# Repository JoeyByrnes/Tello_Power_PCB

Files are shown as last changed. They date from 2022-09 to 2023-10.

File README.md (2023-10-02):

# Tello Power PCB
Hardware Design Files for Tello Power Regulation/Distribution PCB

## Main Power PCB
<hr>
<br>
<p align="center">
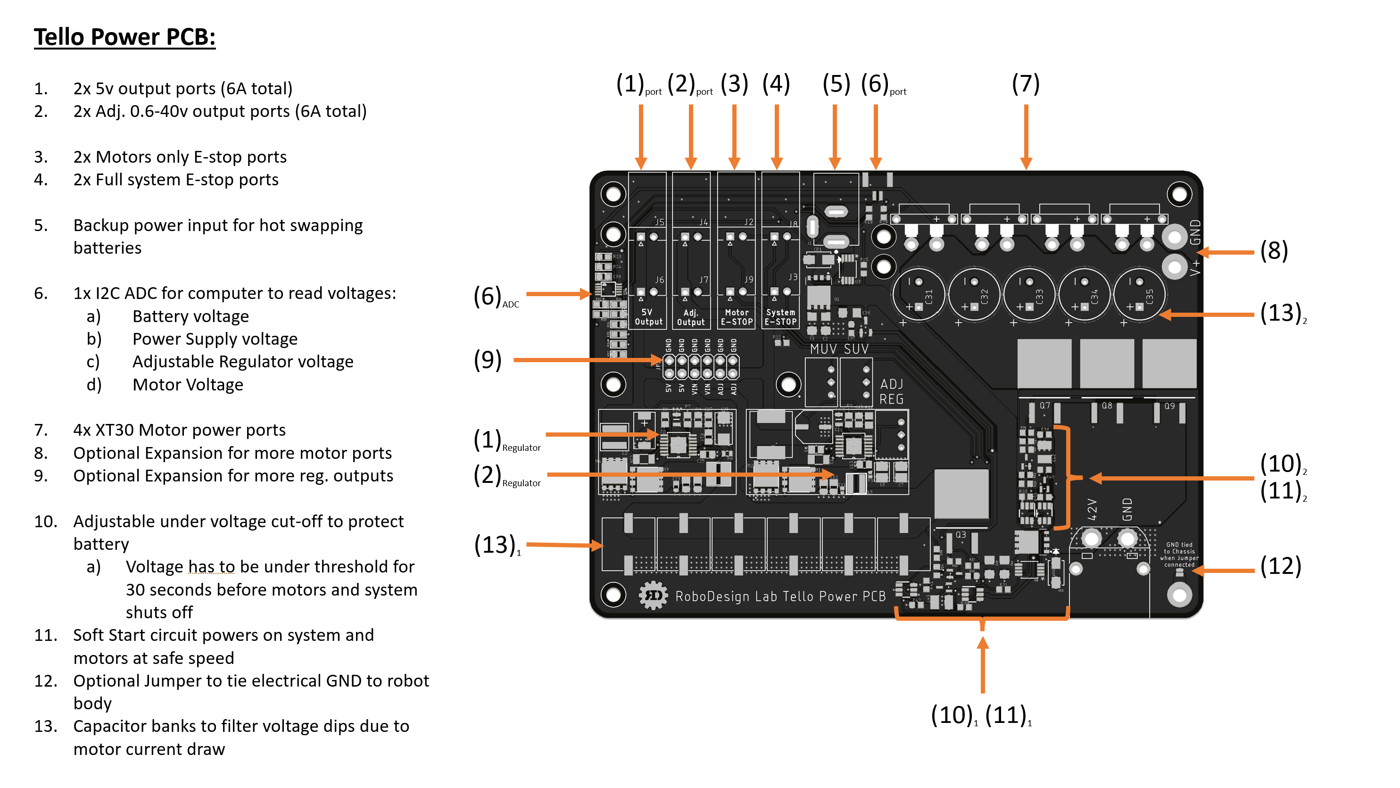
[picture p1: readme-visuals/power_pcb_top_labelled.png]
  
</p>
<p align="center">
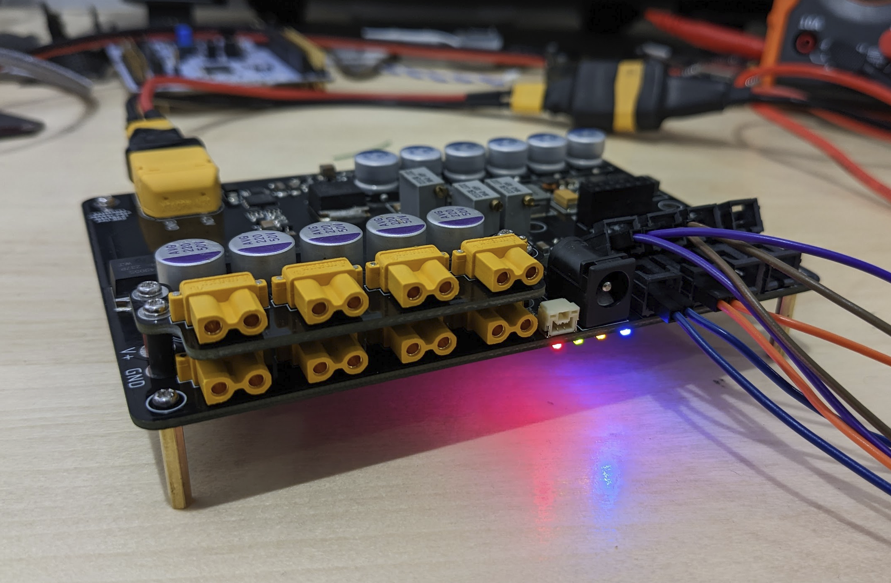
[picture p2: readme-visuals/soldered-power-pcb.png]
  
</p>
<p align="center">
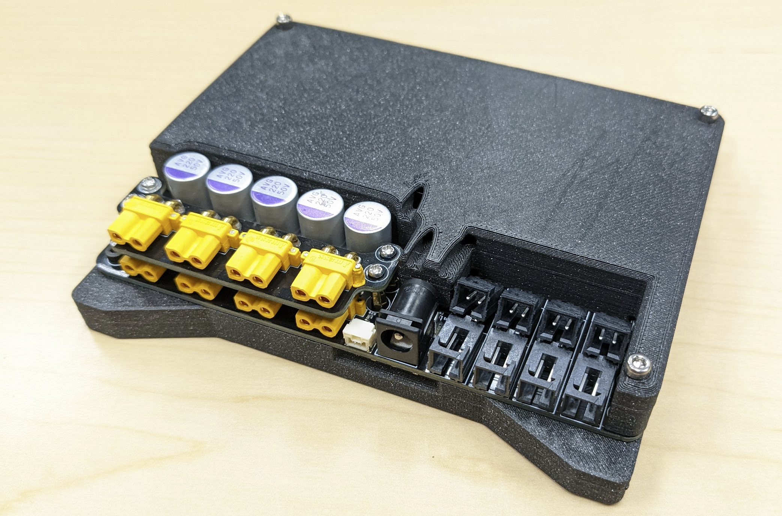
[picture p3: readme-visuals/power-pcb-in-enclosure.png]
  
</p>

<p align="center">
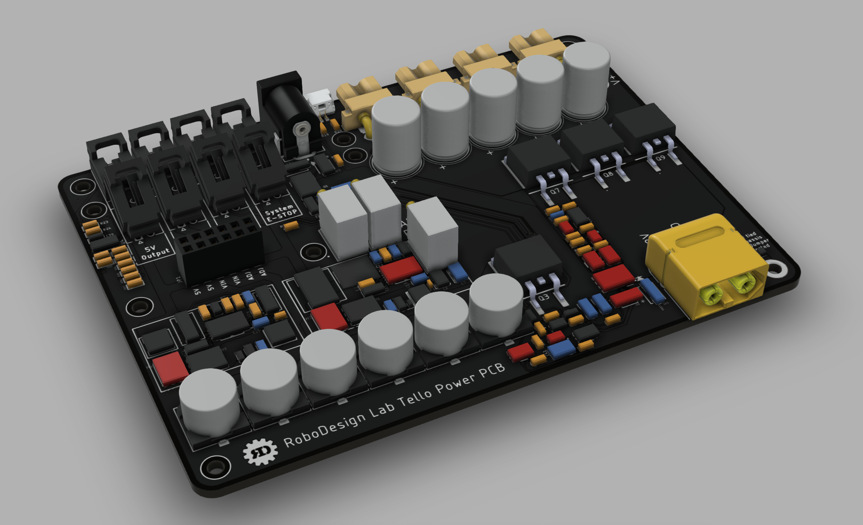
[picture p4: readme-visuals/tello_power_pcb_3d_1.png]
  
</p>
<p align="center">
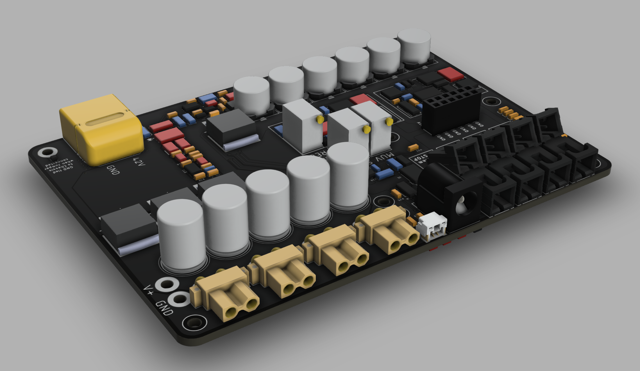
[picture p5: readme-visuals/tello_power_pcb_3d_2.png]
  
</p>
<p align="center">
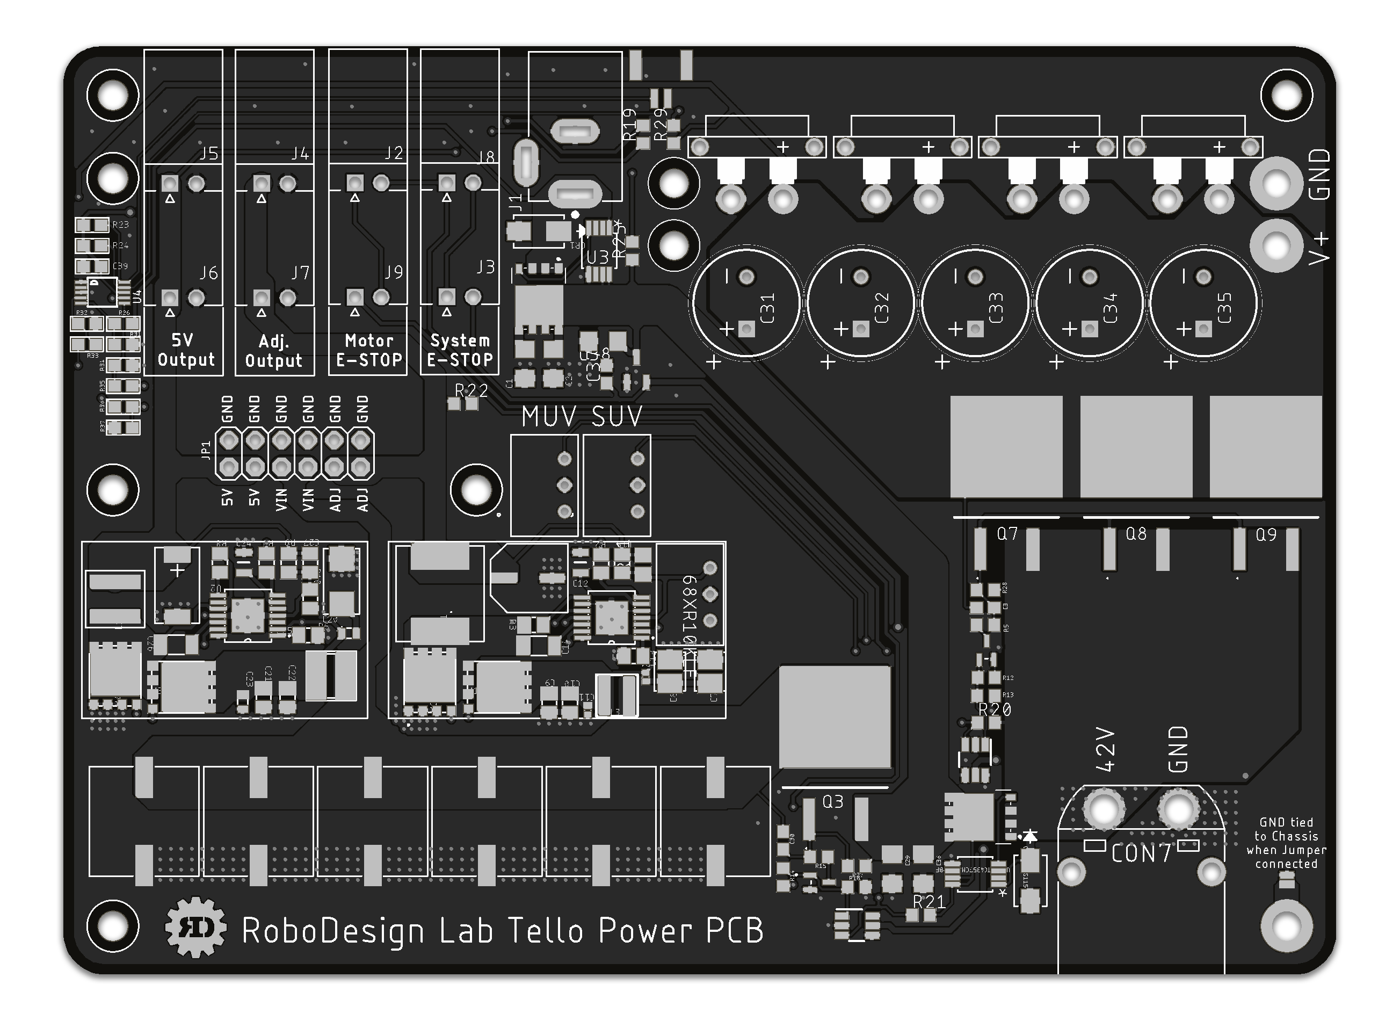
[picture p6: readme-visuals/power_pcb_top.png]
  
</p>
<p align="center">
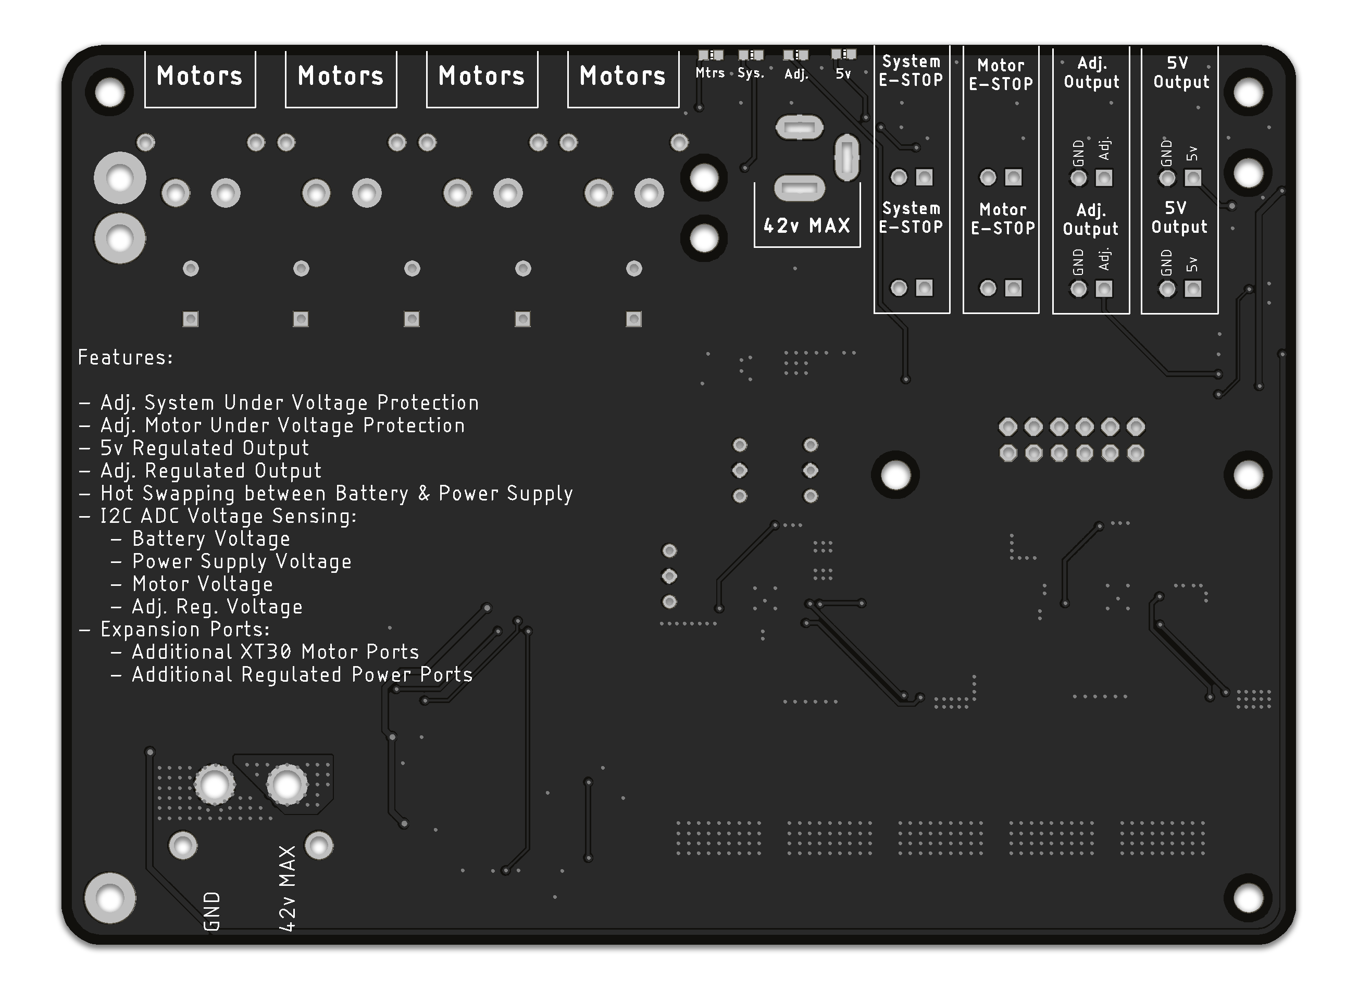
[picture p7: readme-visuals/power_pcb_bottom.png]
  
</p>

<br>

## XT30 Expansion PCB
<hr>
<br>
<p align="center">
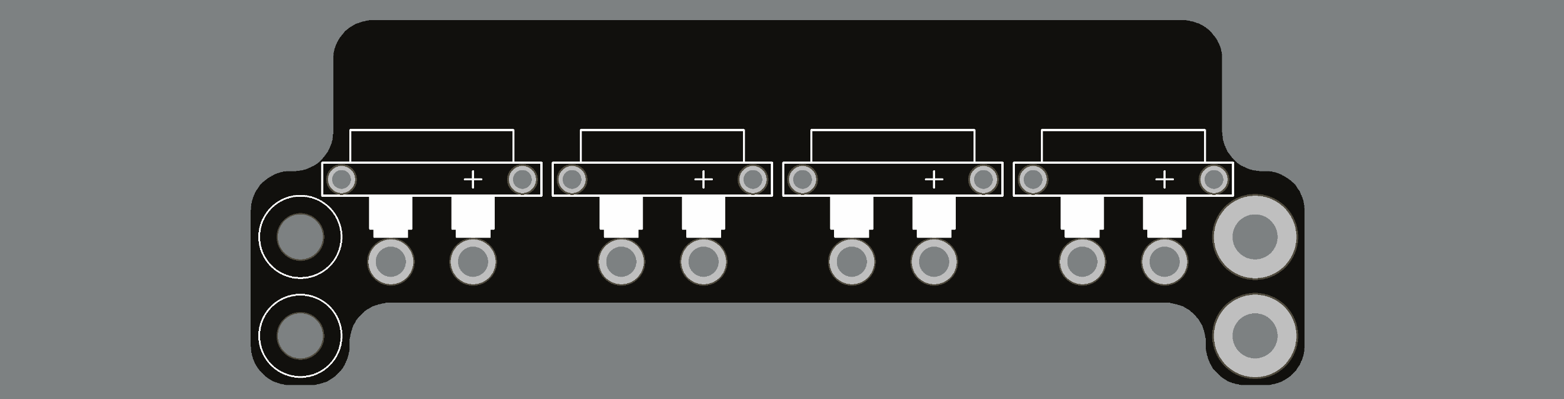
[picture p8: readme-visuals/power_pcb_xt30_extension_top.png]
  
</p>

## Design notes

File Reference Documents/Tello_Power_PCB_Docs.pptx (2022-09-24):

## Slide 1

Tello Power PCB:
1. 2x 5v output ports (6A total)
2. 2x Adj. 0.6-40v output ports (6A total)
3. 2x Motors only E-stop ports
4. 2x Full system E-stop ports
5. Backup power input for hot swapping batteries
6. 1x I2C ADC for computer to read voltages:
  a. Battery voltage
  b. Power Supply voltage
  c. Adjustable Regulator voltage
  d. Motor Voltage
7. 4x XT30 Motor power ports
8. Optional Expansion for more motor ports
9. Optional Expansion for more reg. outputs
10. Adjustable under voltage cut-off to protect battery
  a. Voltage has to be under threshold for 30 seconds before motors and system shuts off
11. Soft Start circuit powers on system and motors at safe speed
12. Optional Jumper to tie electrical GND to robot body
13. Capacitor banks to filter voltage dips due to motor current draw

(1)port

(2)port

(3)

(4)

(5)

(6)port

(7)

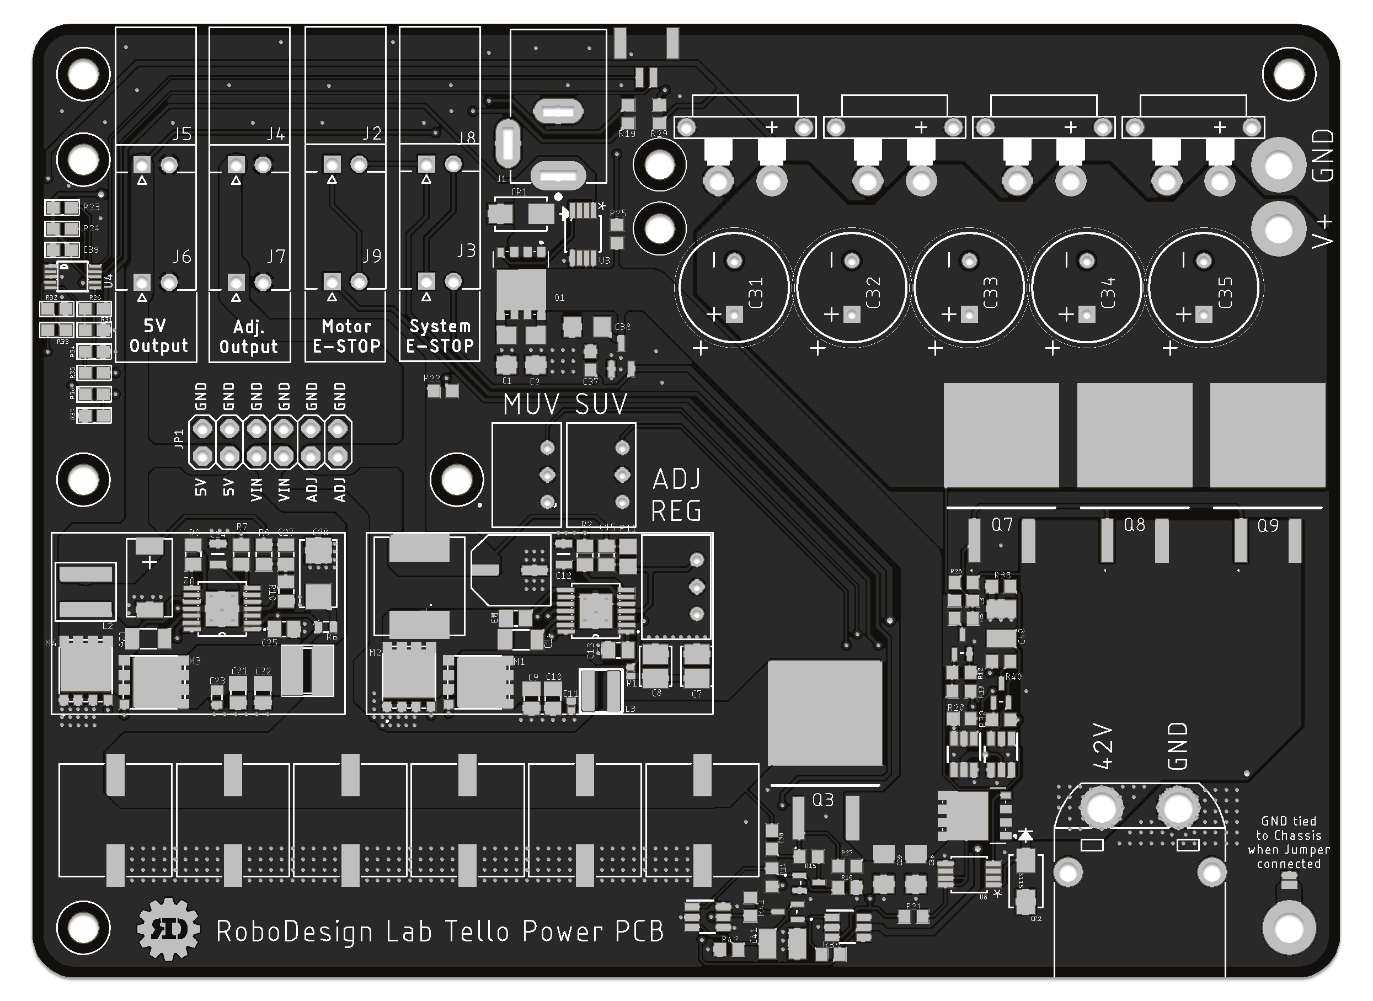
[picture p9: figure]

(8)

(6)ADC

(13)2

(9)

(1)Regulator

(2)Regulator

(10)2

(13)1

(11)2

(12)

(10)1

(11)1

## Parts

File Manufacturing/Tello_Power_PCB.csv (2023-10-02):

Qty | Value | Device | Package | Parts | Description | ARROW_PART_NUMBER | ARROW_PRICE-STOCK | BUILT_BY | CAP | COPYRIGHT | CUI_PURCHASE_URL | DATASHEETURL | DCR | DESCRIPTION | DIGI-KEY_PART_NUMBER | DIGI-KEY_PART_NUMBER_1 | DIGI-KEY_PART_NUMBER_2 | DIGI-KEY_PART_NUMBER_3 | ESR | FREQUENCY | HEIGHT | IDC | IDSMAX | IMAX | IRMS | L | MANUFACTURER_NAME | MANUFACTURER_PART_NUMBER | MF | MFR_NAME | MKTG_PACKAGE | MOUSER_PART_NUMBER | MOUSER_PRICE-STOCK | MOUSER_TESTING_PART_NUMBER | MOUSER_TESTING_PRICE-STOCK | MP | NSID | PACKAGE | POPULARITY | POWER | PURCHASE-URL | QGTYP | QUANTITY | RDSON45 | RDSONAT10V | REFDES | RESISTANCE | RS_PART_NUMBER | RS_PRICE-STOCK | SOURCELIBRARY | SPICEPREFIX | TOLERANCE | TYPE | VDC | VDSMAX | VENDOR
4 |  | LED_LEDCHIP-LED0603 | LED_CHIP-LED0603 | LED1, LED2, LED3, LED4 | LED |  |  |  |  |  |  |  |  |  |  |  |  |  |  |  |  |  |  |  |  |  |  |  |  |  |  |  |  |  |  |  |  |  | 0
1 |  | PINHEAD_PINHD-2X6 | PINHEAD_2X06 | JP1 | PIN HEADER |  |  |  |  |  |  |  |  |  |  |  |  |  |  |  |  |  |  |  |  |  |  |  |  |  |  |  |  |  |  |  |  |  | 1
1 | 1 | 12V--LM3150_CRCW04021R00FKED | 12V--LM3150_0402 | R1 |  |  |  |  |  |  |  |  |  |  |  |  |  |  |  |  |  |  |  |  |  |  | VishayDale | CRCW04021R00FKED |  |  |  |  |  |  |  |  |  |  |  | 0.063 |  |  |  |  |  |  | 1.0 |  |  |  |  | 1.0 |  |  |  | VishayDale
1 | 1.37k | 12V--LM3150_ERJ-6ENF1371V | 12V--LM3150_0805:1 | R3 |  |  |  |  |  |  |  |  |  |  |  |  |  |  |  |  |  |  |  |  |  |  | Panasonic | ERJ6ENF1371V |  |  |  |  |  |  |  |  |  |  |  | 0.125 |  |  |  |  |  |  | 1370.0 |  |  |  |  | 1.0 |  |  |  | Panasonic
1 | 1.58k | 5V-LM3150MH_ERJ-6ENF1581V | 5V-LM3150MH_0805 | R8 |  |  |  |  |  |  |  |  |  |  |  |  |  |  |  |  |  |  |  |  |  |  | Panasonic | ERJ6ENF1581V |  |  |  |  |  |  |  |  |  |  |  | 0.125 |  |  |  |  |  |  | 1580.0 |  |  |  |  | 1.0 |  |  |  | Panasonic
2 | 100K | RCL_R-US_R0603 | RCL_R0603 | R20, R21 | RESISTOR, American symbol |  |  |  |  |  |  |  |  |  |  |  |  |  |  |  |  |  |  |  |  |  |  |  |  |  |  |  |  |  |  |  |  |  | 77 |  |  |  |  |  |  |  |  |  |  |  | R
2 | 100R | RCL_R-US_R0603 | RCL_R0603 | R40, R41 | RESISTOR, American symbol |  |  |  |  |  |  |  |  |  |  |  |  |  |  |  |  |  |  |  |  |  |  |  |  |  |  |  |  |  |  |  |  |  | 77 |  |  |  |  |  |  |  |  |  |  |  | R
1 | 100m | 5V-LM3150MH_ERJ-3RSFR10V | 5V-LM3150MH_0603 | R6 |  |  |  |  |  |  |  |  |  |  |  |  |  |  |  |  |  |  |  |  |  |  | Panasonic | ERJ3RSFR10V |  |  |  |  |  |  |  |  |  |  |  | 0.1 |  |  |  |  |  |  | 0.1 |  |  |  |  | 1.0 |  |  |  | Panasonic
1 | 100nF | 12V--LM3150_C1005X5R1H104K050BB | 12V--LM3150_0402 | C11 |  |  |  |  | 1.0E7 |  |  | httpsproduct.tdk.comensearchcapacitorceramicmlccinfo?part%5Fno%3DC1005X5R1H104K050BB |  |  |  |  |  |  | 0.039064 |  |  |  |  |  | 0.814669 |  | TDK | C1005X5R1H104K050BB |  |  |  |  |  |  |  |  |  |  |  |  |  |  |  |  |  |  |  |  |  |  |  |  |  | 50.0 |  | TDK
1 | 100nF | 5V-LM3150MH_CGA3E2X7R1H104K080AA | 5V-LM3150MH_0603 | C23 |  |  |  |  | 1.0E7 |  |  | httpsproduct.tdk.comensearchcapacitorceramicmlccinfo?part%5Fno%3DCGA3E2X7R1H104K080AA |  |  |  |  |  |  | 0.0296 |  |  |  |  |  | 0.97199 |  | TDK | CGA3E2X7R1H104K080AA |  |  |  |  |  |  |  |  |  |  |  |  |  |  |  |  |  |  |  |  |  |  |  |  |  | 50.0 |  | TDK
6 | 10K | MICROBUILDER_RESISTOR0603 | MICROBUILDER_0603:1 | R23, R24, R26, R33, R35, R36 | Resistors
4 | 10K | RCL_R-US_R0603 | RCL_R0603 | R5, R12, R15, R16 | RESISTOR, American symbol |  |  |  |  |  |  |  |  |  |  |  |  |  |  |  |  |  |  |  |  |  |  |  |  |  |  |  |  |  |  |  |  |  | 77 |  |  |  |  |  |  |  |  |  |  |  | R
1 | 10k | 5V-LM3150MH_CRCW080510K0FKEA | 5V-LM3150MH_0805 | R10 |  |  |  |  |  |  |  |  |  |  |  |  |  |  |  |  |  |  |  |  |  |  | VishayDale | CRCW080510K0FKEA |  |  |  |  |  |  |  |  |  |  |  | 0.125 |  |  |  |  |  |  | 10000.0 |  |  |  |  | 1.0 |  |  |  | VishayDale
2 | 10uF | 5V-LM3150MH_C2012X5R1V106K085AC | 5V-LM3150MH_0805 | C21, C22 |  |  |  |  | 1.0E5 |  |  | httpsproduct.tdk.comensearchcapacitorceramicmlccinfo?part%5Fno%3DC2012X5R1V106K085AC |  |  |  |  |  |  | 0.002818 |  |  |  |  |  | 3.88676 |  | TDK | C2012X5R1V106K085AC |  |  |  |  |  |  |  |  |  |  |  |  |  |  |  |  |  |  |  |  |  |  |  |  |  | 35.0 |  | TDK
4 | 10uF 50v | RCL_C-EUC1206 | RCL_C1206 | C1, C2, C29, C36 | CAPACITOR, European symbol |  |  |  |  |  |  |  |  |  |  |  |  |  |  |  |  |  |  |  |  |  |  |  |  |  |  |  |  |  |  |  |  |  | 13 |  |  |  |  |  |  |  |  |  |  |  | C
1 | 10µF | MICROBUILDER_CAP_CERAMIC0603 | MICROBUILDER_0603:1 | C39 | Ceramic Capacitors
2 | 15nF | CGA4F2C0G1H153J085AA_CGA4F2C0G1H153J085AA | CGA4F2C0G1H153J085AA_CAPC2012X100N | C12, C24 | Capacitor Auto CGA 0805 50V 15nF C0G |  |  |  |  |  |  |  |  | Capacitor Auto CGA 0805 50V 15nF C0G |  |  |  |  |  |  | 1mm |  |  |  |  |  | TDK | CGA4F2C0G1H153J085AA |  |  |  | 810-CGA4F2C0G1H153J | https://www.mouser.com/Search/Refine.aspx?Keyword=810-CGA4F2C0G1H153J |  |  |  |  |  |  |  |  |  |  |  |  |  |  | 9155168 | https://uk.rs-online.com/web/p/products/9155168
2 | 15uF | 12V--LM3150_C2012X5R1V156M125AC | 12V--LM3150_0805:1 | C9, C10 |  |  |  |  | 1.5E5 |  |  | httpsproduct.tdk.cominfoencatalogdatasheetsmlcc%5Fcommercial%5Fgeneral%5Fen.pdf |  |  |  |  |  |  | 0.001669 |  |  |  |  |  | 5.04984 |  | TDK | C2012X5R1V156M125AC |  |  |  |  |  |  |  |  |  |  |  |  |  |  |  |  |  |  |  |  |  |  |  |  |  | 35.0 |  | TDK
8 | 1719740002_1719740002 | 1719740002_1719740002 | 1719740002_MOLEX_1719740002 | J2, J3, J4, J5, J6, J7, J8, J9 | 2.54mm Pitch SL Header, Single Row, Right-Angle, LCP, Shrouded, Through Hole, Matte Tin (Sn) Plating, 2 Circuits |  |  |  |  |  |  |  |  | Connector Header Through Hole, Right Angle 2 position 0.100 (2.54mm) | WM22662-ND |  |  |  |  |  |  |  |  |  |  |  |  |  | Molex |  |  |  |  |  |  | 1719740002 |  | None |  |  | https://pricing.snapeda.com/search/part/1719740002/?ref=eda
4 | 1K | MICROBUILDER_RESISTOR0603 | MICROBUILDER_0603:1 | R31, R32, R34, R37 | Resistors
5 | 1K | RCL_R-US_R0603 | RCL_R0603 | R13, R14, R19, R30, R39 | RESISTOR, American symbol |  |  |  |  |  |  |  |  |  |  |  |  |  |  |  |  |  |  |  |  |  |  |  |  |  |  |  |  |  |  |  |  |  | 77 |  |  |  |  |  |  |  |  |  |  |  | R
1 | 2.2uF | 12V--LM3150_EMK212BJ225KG-T:1 | 12V--LM3150_0805:1 | C13 |  |  |  |  | 2.2E6 |  |  |  |  |  |  |  |  |  | 0.0 |  |  |  |  |  | 0.0 |  | Taiyo Yuden | EMK212BJ225KGT |  |  |  |  |  |  |  |  |  |  |  |  |  |  |  |  |  |  |  |  |  |  |  |  |  | 16.0 |  | Taiyo Yuden
2 | 2.2uF | 12V--LM3150_TPSB475K035R0700 | 12V--LM3150_3528-21 | C7, C8 |  |  |  |  | 4.7E6 |  |  |  |  |  |  |  |  |  | 0.7 |  |  |  |  |  | 0.314 |  | AVX | TPSB475K035R0700 |  |  |  |  |  |  |  |  |  |  |  |  |  |  |  |  |  |  |  |  |  |  |  |  |  | 35.0 |  | AVX
1 | 2.2uF | 5V-LM3150MH_EMK212BJ225KG-T | 5V-LM3150MH_0805 | C25 |  |  |  |  | 2.2E6 |  |  |  |  |  |  |  |  |  | 0.0 |  |  |  |  |  | 0.0 |  | Taiyo Yuden | EMK212BJ225KGT |  |  |  |  |  |  |  |  |  |  |  |  |  |  |  |  |  |  |  |  |  |  |  |  |  | 16.0 |  | Taiyo Yuden
1 | 2.2uF | RCL_C-EUC0603 | RCL_C0603 | C37 | CAPACITOR, European symbol |  |  |  |  |  |  |  |  |  |  |  |  |  |  |  |  |  |  |  |  |  |  |  |  |  |  |  |  |  |  |  |  |  | 52 |  |  |  |  |  |  |  |  |  |  |  | C
1 | 2.2uF | RCL_C-EUC1206 | RCL_C1206 | C38 | CAPACITOR, European symbol |  |  |  |  |  |  |  |  |  |  |  |  |  |  |  |  |  |  |  |  |  |  |  |  |  |  |  |  |  |  |  |  |  | 13 |  |  |  |  |  |  |  |  |  |  |  | C
1 | 2.2uH | 5V-LM3150MH_XAL5030-222MEB | 5V-LM3150MH_XAL5030 | L2 |  |  |  |  |  |  |  |  | 0.01 |  |  |  |  |  |  |  |  | 9.2 |  |  |  | 2.2E6 | Coilcraft | XAL5030222MEB |  |  |  |  |  |  |  |  |  |  |  |  |  |  |  |  |  |  |  |  |  |  |  |  |  |  |  | Coilcraft
2 | 220uF | RCL_C-EUC1210 | RCL_C1210 | C40, C41 | CAPACITOR, European symbol |  |  |  |  |  |  |  |  |  |  |  |  |  |  |  |  |  |  |  |  |  |  |  |  |  |  |  |  |  |  |  |  |  | 0 |  |  |  |  |  |  |  |  |  |  |  | C
5 | 227AVG050MGBJ_227AVG050MGBJ | 227AVG050MGBJ_227AVG050MGBJ | 227AVG050MGBJ_CAPPRD500W60D1025H1350 | C31, C32, C33, C34, C35 | Aluminum Organic Polymer Capacitors 220uF 50V 20% POLYMER/IC | 227AVG050MGBJ | https://www.arrow.com/en/products/227avg050mgbj/illinois-capacitor?region=nac |  |  |  |  |  |  | Aluminum Organic Polymer Capacitors 220uF 50V 20% POLYMER/IC |  |  |  |  |  |  | 13.5mm |  |  |  |  |  | Cornell Dubilier | 227AVG050MGBJ |  |  |  | 598-227AVG050MGBJ | https://www.mouser.co.uk/ProductDetail/CDE-Illinois-Capacitor/227AVG050MGBJ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
4 | 2K | RCL_R-US_R0603 | RCL_R0603 | R25, R27, R28, R29 | RESISTOR, American symbol |  |  |  |  |  |  |  |  |  |  |  |  |  |  |  |  |  |  |  |  |  |  |  |  |  |  |  |  |  |  |  |  |  | 77 |  |  |  |  |  |  |  |  |  |  |  | R
1 | 3.3uF | 5V-LM3150MH_293D335X9035C2TE3 | 5V-LM3150MH_6032-28 | C20 |  |  |  |  | 3.3E6 |  |  |  |  |  |  |  |  |  | 2.1 |  |  |  |  |  | 0.23 |  | VishaySprague | 293D335X9035C2TE3 |  |  |  |  |  |  |  |  |  |  |  |  |  |  |  |  |  |  |  |  |  |  |  |  |  | 35.0 |  | VishaySprague
1 | 3.3uH | XAL4030-332MEB_XAL4030-332MEB | XAL4030-332MEB_XAL4030-332MEB | L3 | Fixed Inductors XAL4030 High Current 3.3 uH 20 % 6.6 A |  |  |  |  |  |  |  |  | Fixed Inductors XAL4030 High Current 3.3 uH 20 % 6.6 A |  |  |  |  |  |  | mm |  |  |  |  |  | COILCRAFT | XAL4030-332MEB |  |  |  | 994-XAL4030-332MEB | https://www.mouser.com/Search/Refine.aspx?Keyword=994-XAL4030-332MEB
1 | 3.9uH | 5V-LM3150MH_NPI43C3R9MTRF | 5V-LM3150MH_IND_NPI43C | L4 |  |  |  |  |  |  |  |  | 0.07 |  |  |  |  |  |  |  |  | 2.0 |  |  |  | 3.9E6 | NIC Components | NPI43C3R9MTRF |  |  |  |  |  |  |  |  |  |  |  |  |  |  |  |  |  |  |  |  |  |  |  |  |  |  |  | NIC Components
1 | 30.073uF 58.181mOhm | 12V--LM3150_PCV1E330MCL1GS | 12V--LM3150_PCV1E330MCL1GS | C16
1 | 300pF | 12V--LM3150_C0805C301J5GACTU | 12V--LM3150_0805:1 | C15 |  |  |  |  | 3.0E10 |  |  | httpwww.kemet.comdocfinder?Partnumber%3DC0805C301J5GACTU |  |  |  |  |  |  | 0.0 |  |  |  |  |  | 0.0 |  | Kemet | C0805C301J5GACTU |  |  |  |  |  |  |  |  |  |  |  |  |  |  |  |  |  |  |  |  |  |  |  |  |  | 50.0 |  | Kemet
1 | 30V | 12V--LM3150_CSD17579Q5A:1 | 12V--LM3150_TRANS_NEXFET_Q5A:1 | M1 |  |  |  |  |  |  |  | httpwww.ti.comlitdssymlinkCSD17579Q5A.pdf |  |  |  |  |  |  |  |  |  |  | 14.0A |  |  |  | Texas Instruments | CSD17579Q5A |  |  |  |  |  |  |  |  |  |  |  |  |  | 5.4nC | 1 |  | 0.0084Ohm |  |  |  |  |  |  |  |  |  | 30.0V | Texas Instruments
1 | 30V | 5V-LM3150MH_CSD17579Q5A | 5V-LM3150MH_TRANS_NEXFET_Q5A | M3 |  |  |  |  |  |  |  | httpwww.ti.comlitdssymlinkCSD17579Q5A.pdf |  |  |  |  |  |  |  |  |  |  | 14.0A |  |  |  | Texas Instruments | CSD17579Q5A |  |  |  |  |  |  |  |  |  |  |  |  |  | 5.4nC | 1 |  | 0.0084Ohm |  |  |  |  |  |  |  |  |  | 30.0V | Texas Instruments
1 | 332k | 12V--LM3150_ERJ-6ENF3323V | 12V--LM3150_0805:1 | R2 |  |  |  |  |  |  |  |  |  |  |  |  |  |  |  |  |  |  |  |  |  |  | Panasonic | ERJ6ENF3323V |  |  |  |  |  |  |  |  |  |  |  | 0.125 |  |  |  |  |  |  | 332000.0 |  |  |  |  | 1.0 |  |  |  | Panasonic
1 | 33k | RCL_R-US_R0805 | RCL_R0805 | R11 | RESISTOR, American symbol |  |  |  |  |  |  |  |  |  |  |  |  |  |  |  |  |  |  |  |  |  |  |  |  |  |  |  |  |  |  |  |  |  | 0 |  |  |  |  |  |  |  |  |  |  |  | R
1 | 470nF | 12V--LM3150_ECPU1C474MA5:1 | 12V--LM3150_1206:1 | C14 |  |  |  |  | 4.7E7 |  |  | httpwww.panasonic.comindustrialcomponentspdfef038%5Fecpu%5Fdne.pdf |  |  |  |  |  |  | 0.0 |  |  |  |  |  | 0.0 |  | Panasonic | ECPU1C474MA5 |  |  |  |  |  |  |  |  |  |  |  |  |  |  |  |  |  |  |  |  |  |  |  |  |  | 16.0 |  | Panasonic
1 | 470nF | 5V-LM3150MH_ECPU1C474MA5 | 5V-LM3150MH_1206 | C26 |  |  |  |  | 4.7E7 |  |  | httpwww.panasonic.comindustrialcomponentspdfef038%5Fecpu%5Fdne.pdf |  |  |  |  |  |  | 0.0 |  |  |  |  |  | 0.0 |  | Panasonic | ECPU1C474MA5 |  |  |  |  |  |  |  |  |  |  |  |  |  |  |  |  |  |  |  |  |  |  |  |  |  | 16.0 |  | Panasonic
2 | 47nF | RCL_C-EUC0603 | RCL_C0603 | C3, C30 | CAPACITOR, European symbol |  |  |  |  |  |  |  |  |  |  |  |  |  |  |  |  |  |  |  |  |  |  |  |  |  |  |  |  |  |  |  |  |  | 52 |  |  |  |  |  |  |  |  |  |  |  | C
1 | 51.1k | 5V-LM3150MH_ERJ-6ENF5112V | 5V-LM3150MH_0805 | R7 |  |  |  |  |  |  |  |  |  |  |  |  |  |  |  |  |  |  |  |  |  |  | Panasonic | ERJ6ENF5112V |  |  |  |  |  |  |  |  |  |  |  | 0.125 |  |  |  |  |  |  | 51100.0 |  |  |  |  | 1.0 |  |  |  | Panasonic
1 | 5K | RCL_R-US_R0603 | RCL_R0603 | R22 | RESISTOR, American symbol |  |  |  |  |  |  |  |  |  |  |  |  |  |  |  |  |  |  |  |  |  |  |  |  |  |  |  |  |  |  |  |  |  | 77 |  |  |  |  |  |  |  |  |  |  |  | R
2 | 5V-LM3150MH_LM3150MH/NOPB | 5V-LM3150MH_LM3150MH/NOPB | 5V-LM3150MH_MXA14A | U1, U2 |  |  |  |  |  |  |  | httpwww.ti.comproductlm3150 |  |  |  |  |  |  |  | 1000000.0 |  |  |  | 12.0 |  |  | Texas Instruments | LM3150MHNOPB |  |  | NA |  |  |  |  |  | LM3150MHNOPB | NA |  |  |  |  |  |  |  |  |  |  |  |  |  |  |  |  |  | Texas Instruments
1 | 60V | 12V--LM3150_CSD18537NQ5A:1 | 12V--LM3150_TRANS_NEXFET_Q5A:1 | M2 |  |  |  |  |  |  |  | httpwww.ti.comlitdssymlinkcsd18537nq5a.pdf |  |  |  |  |  |  |  |  |  |  | 50.0 |  |  |  | Texas Instruments | CSD18537NQ5A |  |  |  |  |  |  |  |  |  |  |  |  |  | 14.0 | 1 | 0.014559 |  |  |  |  |  |  |  |  |  |  | 60.0 | Texas Instruments
1 | 60V | 5V-LM3150MH_CSD18537NQ5A | 5V-LM3150MH_TRANS_NEXFET_Q5A | M4 |  |  |  |  |  |  |  | httpwww.ti.comlitdssymlinkcsd18537nq5a.pdf |  |  |  |  |  |  |  |  |  |  | 50.0 |  |  |  | Texas Instruments | CSD18537NQ5A |  |  |  |  |  |  |  |  |  |  |  |  |  | 14.0 | 1 | 0.014559 |  |  |  |  |  |  |  |  |  |  | 60.0 | Texas Instruments
2 | 62K | RCL_R-US_R0603 | RCL_R0603 | R38, R42 | RESISTOR, American symbol |  |  |  |  |  |  |  |  |  |  |  |  |  |  |  |  |  |  |  |  |  |  |  |  |  |  |  |  |  |  |  |  |  | 77 |  |  |  |  |  |  |  |  |  |  |  | R
1 | 62pF | 5V-LM3150MH_CL21C620JBANNNC | 5V-LM3150MH_0805 | C27 |  |  |  |  | 6.2E11 |  |  | httpwww.samsungsem.comservletFileDownload?type%3Dspec%26file%3DCL21C620JBANNNC.pdf |  |  |  |  |  |  | 0.0 |  |  |  |  |  | 0.0 |  | Samsung ElectroMechanics | CL21C620JBANNNC |  |  |  |  |  |  |  |  |  |  |  |  |  |  |  |  |  |  |  |  |  |  |  |  |  | 50.0 |  | Samsung ElectroMechanics
3 | 68XR10KLF_68XR10KLF | 68XR10KLF_68XR10KLF | 68XR10KLF_RES3_68X_TTE | R4, R17, R18 |  |  |  |  |  | Copyright (C) 2022 Ultra Librarian. All rights reserved. |  |  |  |  |  | 987-1112-ND |  |  |  |  |  |  |  |  |  |  |  | 68XR10KLF |  | TT Electronics
1 | 73.2k | 5V-LM3150MH_CRCW080573K2FKEA | 5V-LM3150MH_0805 | R9 |  |  |  |  |  |  |  |  |  |  |  |  |  |  |  |  |  |  |  |  |  |  | VishayDale | CRCW080573K2FKEA |  |  |  |  |  |  |  |  |  |  |  | 0.125 |  |  |  |  |  |  | 73200.0 |  |  |  |  | 1.0 |  |  |  | VishayDale
1 | 8.2uH | 12V--LM3150_74437358082 | 12V--LM3150_WE-LHMI_8040 | L1 |  |  |  |  |  |  |  | httpkatalog.we%2Donline.depbsdatasheet74437358082.pdf | 0.045 |  |  |  |  |  |  |  |  | 13.0 |  |  |  | 8.2E6 | Wurth Elektronik | 74437358082 |  |  |  |  |  |  |  |  |  |  |  |  |  |  |  |  |  |  |  |  |  |  |  |  |  |  |  | Wurth Elektronik
1 | ADS1015IDGST | MICROBUILDER_ADC_ADS1015 | MICROBUILDER_MSOP10 | U4 | ADS1015 - 12-bit 4-Channel I2C ADC with Internal PGA
4 | AMASS_XT30PW-F | AMASS_XT30PW-F | AMASS_XT30PW-F | CON1, CON2, CON3, CON4 | AMASS XT30 connector
1 | AMASS_XT60PW-M | AMASS_XT60PW-M | AMASS_XT60PW-M | CON7 | AMASS XT60 connector
2 | BSC027N06LS5ATMA1_BSC027N06LS5ATMA1 | BSC027N06LS5ATMA1_BSC027N06LS5ATMA1 | BSC027N06LS5ATMA1_BSC027N06LS5ATMA1 | Q1, Q2 | MOSFET DIFFERENTIATED MOSFETS | BSC027N06LS5ATMA1 | https://www.arrow.com/en/products/bsc027n06ls5atma1/infineon-technologies-ag |  |  |  |  |  |  | MOSFET DIFFERENTIATED MOSFETS |  |  |  |  |  |  | 1mm |  |  |  |  |  | Infineon | BSC027N06LS5ATMA1 |  |  |  | 726-BSC027N06LS5ATMA | https://www.mouser.co.uk/ProductDetail/Infineon-Technologies/BSC027N06LS5ATMA1?qs=HXFqYaX1Q2z6vEIhZX7Vzw%3D%3D
4 | DMN67D8LW-13_DMN67D8LW-13 | DMN67D8LW-13_DMN67D8LW-13 | DMN67D8LW-13_DMN67D8LW-13_DIO | U5, U6, U7, U12 |  |  |  |  |  | Copyright (C) 2022 Ultra Librarian. All rights reserved. |  |  |  |  |  | DMN67D8LW-13DITR-ND | DMN67D8LW-13DICT-ND | DMN67D8LW-13DIDKR-ND |  |  |  |  |  |  |  |  |  | DMN67D8LW-13 |  | Diodes Inc
1 | EEF-CX0J151XR | 5V-LM3150MH_CUSTOM_CAP | 5V-LM3150MH_C2917 | C28
4 | IXTA96P085T_IXTA96P085T | IXTA96P085T_IXTA96P085T | IXTA96P085T_IXTA96P085T | Q3, Q7, Q8, Q9 | MOSFET -96 Amps -85V 0.013 Rds | IXTA96P085T | https://www.arrow.com/en/products/ixta96p085t/ixys |  |  |  |  |  |  | MOSFET -96 Amps -85V 0.013 Rds |  |  |  |  |  |  | 4.83mm |  |  |  |  |  | LITTELFUSE | IXTA96P085T |  |  |  | 747-IXTA96P085T | https://www.mouser.co.uk/ProductDetail/IXYS/IXTA96P085T?qs=cvHLLyFtoE0pYb9zzr%252BXGQ%3D%3D
2 | LTC4357_LTC4357CMS8TRPBF | LTC4357_LTC4357CMS8TRPBF | LTC4357_MSOP-8_MS_LIT | U3, U8 |  |  |  | EMA_UL_Team |  |  |  |  |  |  |  |  |  |  |  |  |  |  |  |  |  |  |  | ltc4357cms8#trpbf |  |  |  |  |  |  |  |  |  |  |  |  |  |  |  |  |  |  |  |  |  | LinearTech_2016_03_08 |  |  |  |  |  | Linear Technology
1 | MCP1792T-5002H_MCP1792T-5002H/CB | MCP1792T-5002H_MCP1792T-5002H/CB | MCP1792T-5002H_SOT-23A_CB_MCH | U13 |  |  |  |  |  | Copyright (C) 2022 Ultra Librarian. All rights reserved. |  |  |  |  |  | MCP1792T-5002H/CBTR-ND | MCP1792T-5002H/CBCT-ND | MCP1792T-5002H/CBDKR-ND |  |  |  |  |  |  |  |  |  | MCP1792T-5002H/CB |  | Microchip
6 | PCR1H820MCL1GS_PCR1H820MCL1GS | PCR1H820MCL1GS_PCR1H820MCL1GS | PCR1H820MCL1GS_CAP_PC_10X8_NCH | C4, C5, C6, C17, C18, C19 |  |  |  |  |  | Copyright (C) 2022 Ultra Librarian. All rights reserved. |  |  |  |  |  | 493-13771-1-ND | 493-13771-2-ND | 493-13771-6-ND |  |  |  |  |  |  |  |  |  | PCR1H820MCL1GS |  | Nichicon
1 | PJ-002A_PJ-002A | PJ-002A_PJ-002A | PJ-002A_CUI_PJ-002A | J1 | 2.0 mm Center Pin, 2.5 A, Right Angle, Through Hole, Dc Power Jack Connector |  |  |  |  |  | https://www.cuidevices.com/product/interconnect/connectors/dc-power-connectors/jacks/pj-002a |  |  | 2.0 x 6.5 mm, 2.5 A, Horizontal, Through Hole, Dc Power Jack Connector | CP-002A-ND |  |  |  |  |  |  |  |  |  |  |  |  |  | CUI Devices |  |  |  |  |  |  | PJ-002A |  | None |  |  | https://pricing.snapeda.com/search/part/PJ-002A/?ref=eda
1 | SM02B-GHS-TB_SM02BGHSTBLFSN | SM02B-GHS-TB_SM02BGHSTBLFSN | SM02B-GHS-TB_CONN_SM02BGHSTB_JST | J10 |  |  |  |  |  | Copyright (C) 2022 Ultra Librarian. All rights reserved. |  |  |  |  |  | 455-1564-2-ND | 455-1564-1-ND | 455-1564-6-ND |  |  |  |  |  |  |  |  |  | SM02BGHSTBLFSN |  | JST
1 | SPARKFUN-JUMPERS_JUMPER-SMT_2_NC_PASTE_NO-SILK | SPARKFUN-JUMPERS_JUMPER-SMT_2_NC_PASTE_NO-SILK | SPARKFUN-JUMPERS_SMT-JUMPER_2_NC_PASTE_NO-SILK | JP2 | Normally closed solder jumper
2 | STPS1150A_STPS1150A | STPS1150A_STPS1150A | STPS1150A_SMA_STM | CR1, CR2 |  |  |  | EMA_UL_Team |  |  |  |  |  |  |  |  |  |  |  |  |  |  |  |  |  |  |  | STPS1150A |  |  |  |  |  |  |  |  |  |  |  |  |  |  |  |  |  |  |  |  |  | Update_to_database_2020-11-24 |  |  |  |  |  | STMicroelectronics
4 | TLV6713DDC_TLV6713DDCTDDC0006A_M | TLV6713DDC_TLV6713DDCTDDC0006A_M | TLV6713DDC_DDC0006A_M | U9, U10, U11, U14 |  |  |  |  |  | Copyright (C) 2022 Ultra Librarian. All rights reserved. |  |  |  |  |  | 296-49090-1-ND | 296-49090-2-ND | 296-49090-6-ND |  |  |  |  |  |  |  |  |  | TLV6713DDCT |  | Texas Instruments |  |  |  |  |  |  |  |  |  |  |  |  |  |  |  | RefDes |  |  |  |  |  |  | TYPE

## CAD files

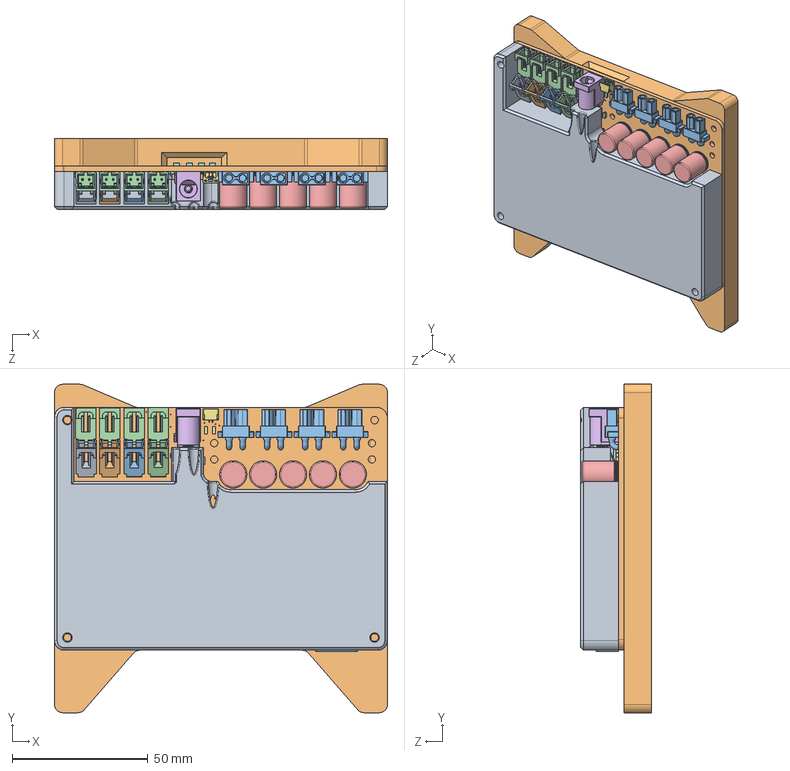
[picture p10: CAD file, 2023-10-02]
3D/Power_PCB_In_Prints.SLDASM
122.5 x 120.8 x 26.0 mm
Power_PCB_Mount
12V--LM3150_1206_1.stp
12V--LM3150_PCV1E330MCL1GS.stp
12V--LM3150_WE-LHMI_8040.stp
5V-LM3150MH_1206.stp
5V-LM3150MH_6032-28.stp
5V-LM3150MH_C2917.stp
5V-LM3150MH_IND_NPI43C.stp
5V-LM3150MH_XAL5030.stp
AMASS_XT60PW-M.stp
MCP1792T-5002H_SOT-23A_CB_MCH.stp
MICROBUILDER_MSOP10.stp
RCL_R0805.stp
SPARKFUN-JUMPERS_SMT-JUMPER_2_NC_PASTE_NO-SILK.stp
XAL4030-332MEB_XAL4030-332MEB.stp
1719740002_MOLEX_1719740002 (1).stp
1719740002_MOLEX_1719740002 (2).stp
1719740002_MOLEX_1719740002 (3).stp
1719740002_MOLEX_1719740002 (4).stp
PINHEAD_2X06.stp
PJ-002A_CUI_PJ-002A.stp
SM02B-GHS-TB_CONN_SM02BGHSTB_JST.stp
12V--LM3150_0402.stp x 2
12V--LM3150_0805_1.stp x 6
12V--LM3150_3528-21.stp x 2
12V--LM3150_TRANS_NEXFET_Q5A_1.stp x 2
1719740002_MOLEX_1719740002.stp x 4
227AVG050MGBJ_CAPPRD500W60D1025H1350.stp x 5
5V-LM3150MH_0603.stp x 2
5V-LM3150MH_0805.stp x 8
5V-LM3150MH_MXA14A.stp x 2
5V-LM3150MH_TRANS_NEXFET_Q5A.stp x 2
68XR10KLF_RES3_68X_TTE.stp x 3
AMASS_XT30PW-F.stp x 4
BSC027N06LS5ATMA1_BSC027N06LS5ATMA1.stp x 2
CGA4F2C0G1H153J085AA_CAPC2012X100N.stp x 2
DMN67D8LW-13_DMN67D8LW-13_DIO.stp x 4
IXTA96P085T_IXTA96P085T.stp x 4
LED_CHIP-LED0603.stp x 4
LTC4357_MSOP-8_MS_LIT.stp x 2
MICROBUILDER_0603_1.stp x 11
PCR1H820MCL1GS_CAP_PC_10X8_NCH.stp x 6
RCL_C0603.stp x 3
RCL_C1206.stp x 5
RCL_C1210.stp x 2
RCL_R0603.stp x 20
STPS1150A_SMA_STM.stp x 2
TLV6713DDC_DDC0006A_M.stp x 4
Board.stp
Power_PCB_Cover

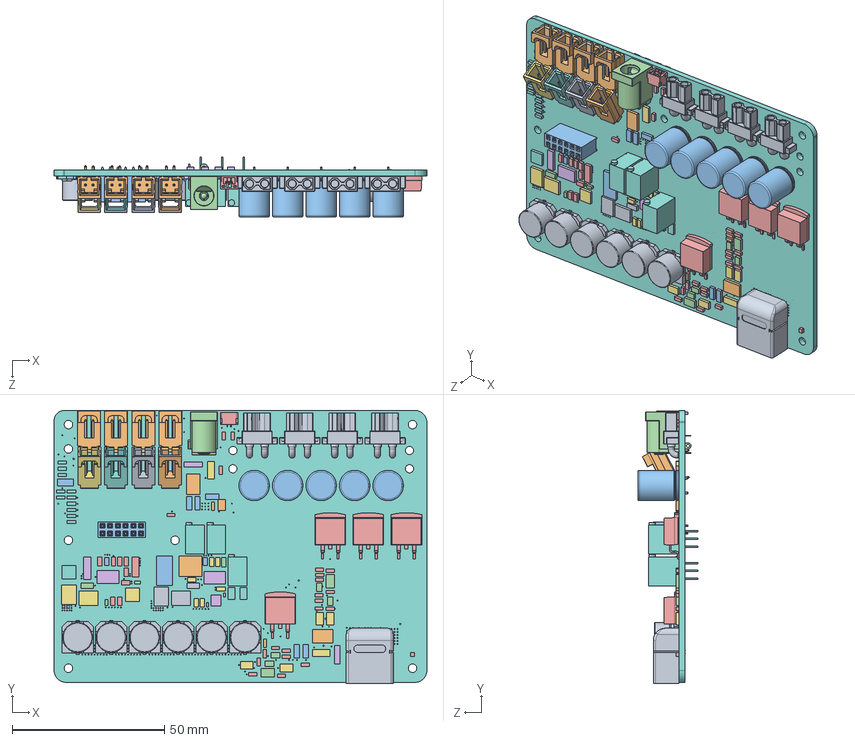
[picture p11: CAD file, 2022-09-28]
3D/Tello_Power_PCB.SLDASM
122.5 x 89.7 x 19.9 mm
12V--LM3150_1206_1.stp
12V--LM3150_PCV1E330MCL1GS.stp
12V--LM3150_WE-LHMI_8040.stp
5V-LM3150MH_1206.stp
5V-LM3150MH_6032-28.stp
5V-LM3150MH_C2917.stp
5V-LM3150MH_IND_NPI43C.stp
5V-LM3150MH_XAL5030.stp
AMASS_XT60PW-M.stp
MCP1792T-5002H_SOT-23A_CB_MCH.stp
MICROBUILDER_MSOP10.stp
RCL_R0805.stp
SPARKFUN-JUMPERS_SMT-JUMPER_2_NC_PASTE_NO-SILK.stp
XAL4030-332MEB_XAL4030-332MEB.stp
1719740002_MOLEX_1719740002 (1).stp
1719740002_MOLEX_1719740002 (2).stp
1719740002_MOLEX_1719740002 (3).stp
1719740002_MOLEX_1719740002 (4).stp
PINHEAD_2X06.stp
PJ-002A_CUI_PJ-002A.stp
SM02B-GHS-TB_CONN_SM02BGHSTB_JST.stp
12V--LM3150_0402.stp x 2
12V--LM3150_0805_1.stp x 6
12V--LM3150_3528-21.stp x 2
12V--LM3150_TRANS_NEXFET_Q5A_1.stp x 2
1719740002_MOLEX_1719740002.stp x 4
227AVG050MGBJ_CAPPRD500W60D1025H1350.stp x 5
5V-LM3150MH_0603.stp x 2
5V-LM3150MH_0805.stp x 8
5V-LM3150MH_MXA14A.stp x 2
5V-LM3150MH_TRANS_NEXFET_Q5A.stp x 2
68XR10KLF_RES3_68X_TTE.stp x 3
AMASS_XT30PW-F.stp x 4
BSC027N06LS5ATMA1_BSC027N06LS5ATMA1.stp x 2
CGA4F2C0G1H153J085AA_CAPC2012X100N.stp x 2
DMN67D8LW-13_DMN67D8LW-13_DIO.stp x 4
IXTA96P085T_IXTA96P085T.stp x 4
LED_CHIP-LED0603.stp x 4
LTC4357_MSOP-8_MS_LIT.stp x 2
MICROBUILDER_0603_1.stp x 11
PCR1H820MCL1GS_CAP_PC_10X8_NCH.stp x 6
RCL_C0603.stp x 3
RCL_C1206.stp x 5
RCL_C1210.stp x 2
RCL_R0603.stp x 20
STPS1150A_SMA_STM.stp x 2
TLV6713DDC_DDC0006A_M.stp x 4
Board.stp

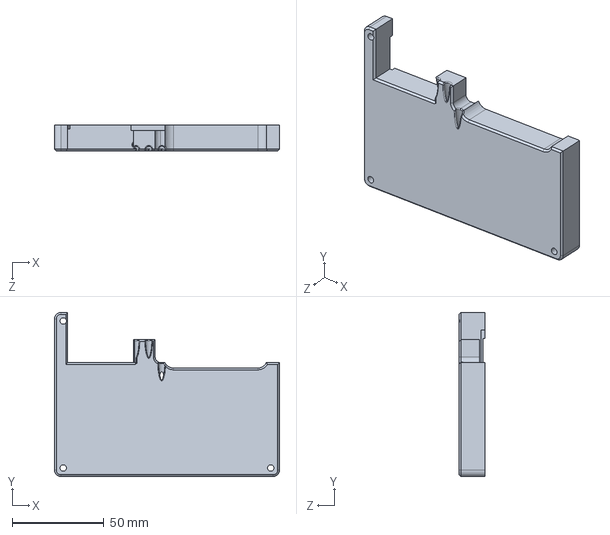
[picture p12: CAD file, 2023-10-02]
3D/Power_PCB_Cover.SLDPRT
122.5 x 89.3 x 14.0 mm

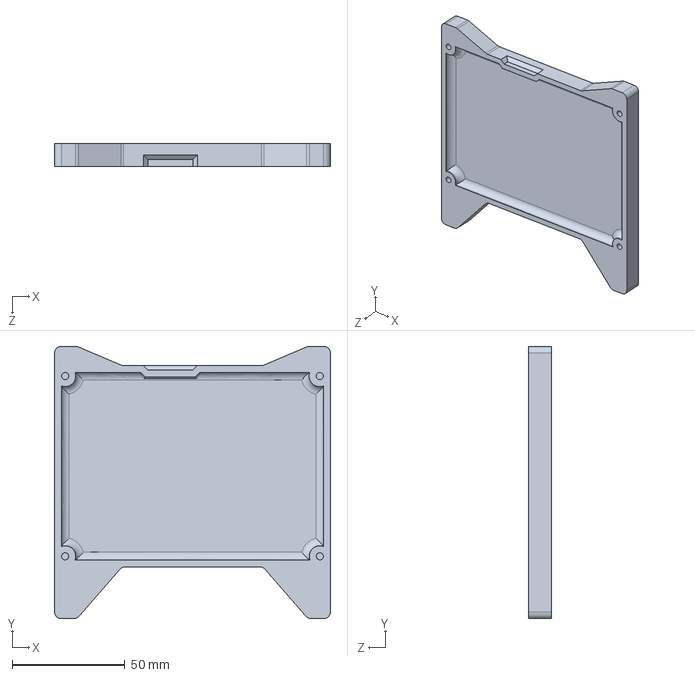
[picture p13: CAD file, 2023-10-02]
3D/Power_PCB_Mount.SLDPRT
122.5 x 120.8 x 10.0 mm

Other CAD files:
3D/Power_PCB_Cover.3mf
3D/Power_PCB_Cover.STL
3D/Power_PCB_Mount.STL

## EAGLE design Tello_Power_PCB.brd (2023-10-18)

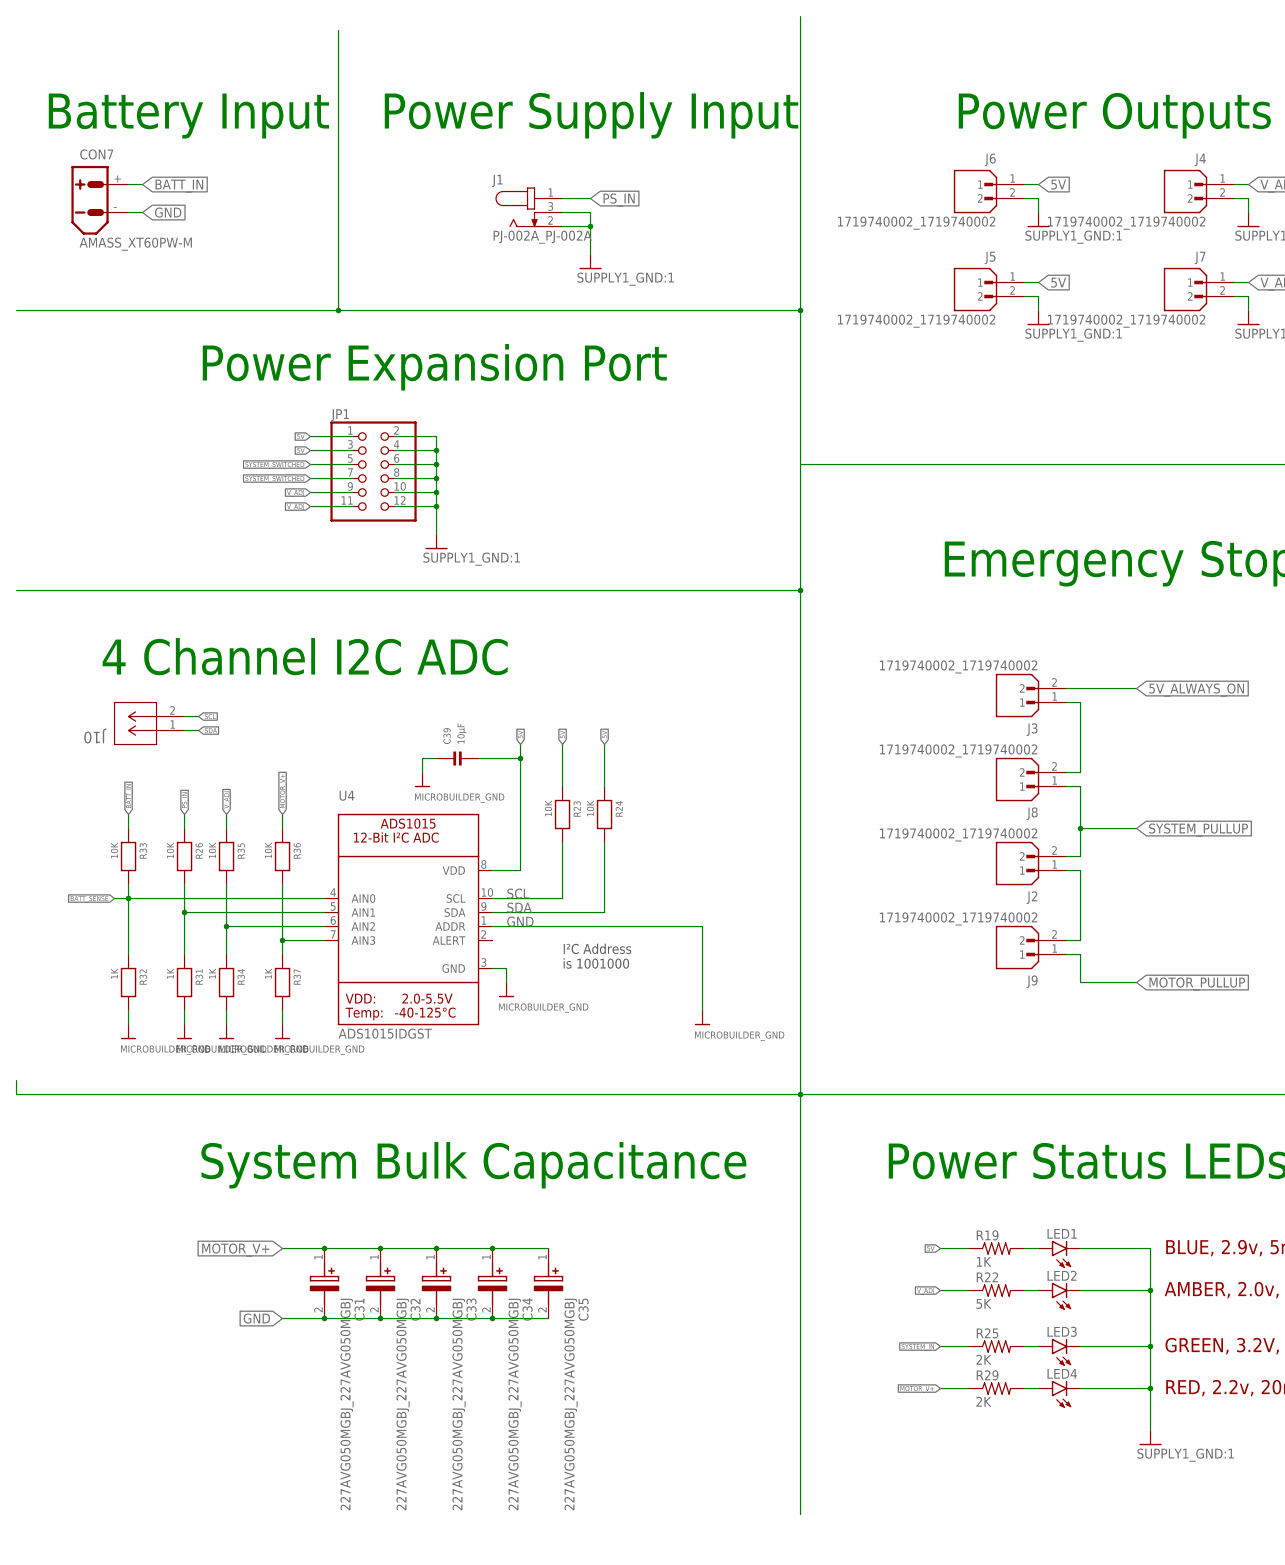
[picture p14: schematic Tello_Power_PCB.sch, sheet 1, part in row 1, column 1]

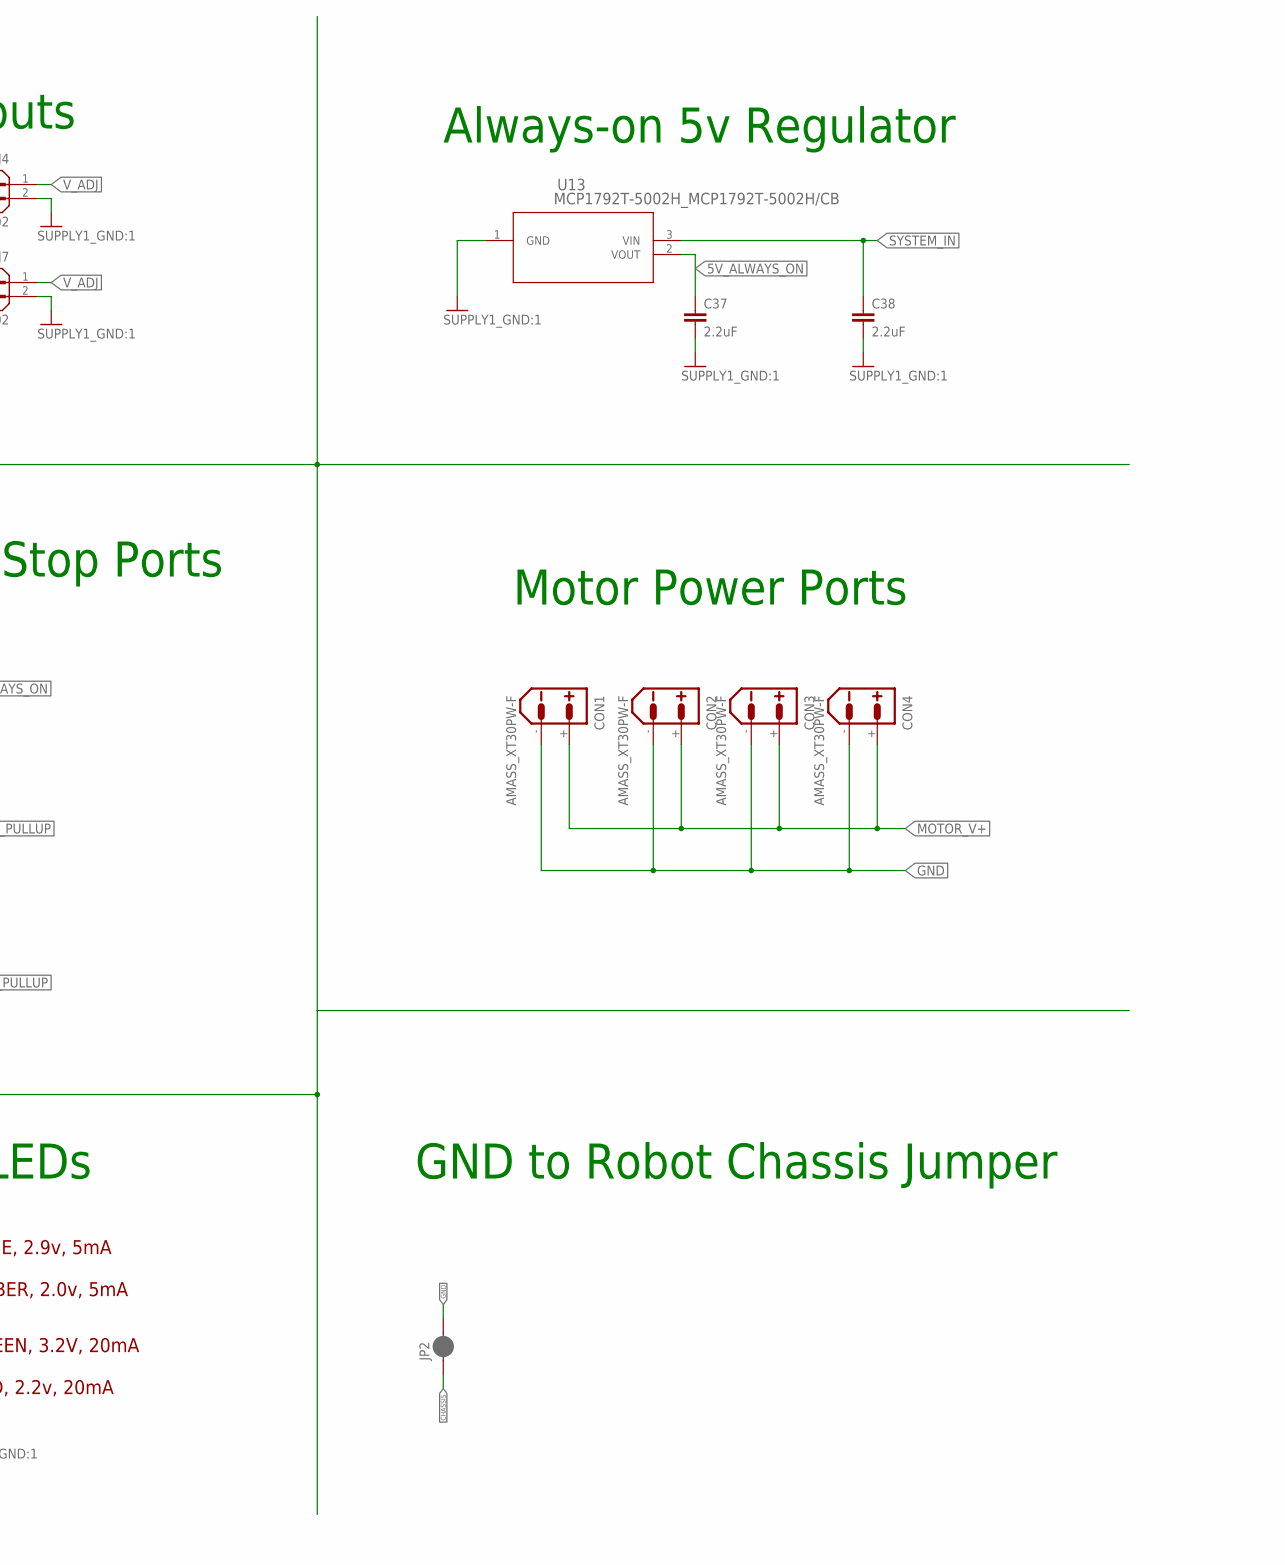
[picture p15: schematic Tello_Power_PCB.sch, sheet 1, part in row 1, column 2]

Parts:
C31, C32, C33, C34, C35: 227AVG050MGBJ_227AVG050MGBJ; 227AVG050MGBJ_CAPPRD500W60D1025H1350
C37: 2.2uF; RCL_C0603
C38: 2.2uF; RCL_C1206
C39: 10µF; MICROBUILDER_0603:1
CON1, CON2, CON3, CON4: AMASS_XT30PW-F
CON7: AMASS_XT60PW-M
J1: PJ-002A_PJ-002A; PJ-002A_CUI_PJ-002A
J2, J3, J4, J5, J6, J7, J8, J9: 1719740002_1719740002; 1719740002_MOLEX_1719740002
J10: SM02B-GHS-TB_SM02BGHSTBLFSN; SM02B-GHS-TB_CONN_SM02BGHSTB_JST
JP1: PINHEAD_PINHD-2X6; PINHEAD_2X06
JP2: SPARKFUN-JUMPERS_JUMPER-SMT_2_NC_PASTE_NO-SILK; SPARKFUN-JUMPERS_SMT-JUMPER_2_NC_PASTE_NO-SILK
LED1, LED2, LED3, LED4: LED_LEDCHIP-LED0603; LED_CHIP-LED0603
R19: 1K; RCL_R0603
R22: 5K; RCL_R0603
R23, R24, R26, R33, R35, R36: 10K; MICROBUILDER_0603:1
R25, R29: 2K; RCL_R0603
R31, R32, R34, R37: 1K; MICROBUILDER_0603:1
U4: ADS1015IDGST; MICROBUILDER_MSOP10
U13: MCP1792T-5002H_MCP1792T-5002H/CB; MCP1792T-5002H_SOT-23A_CB_MCH

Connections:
5V: C39.2, J5.1, J6.1, JP1.1, JP1.3, R19.1, R23.1, R24.1, U4.8 (VDD); also elsewhere on the board
5V_ALWAYS_ON: C37.1, J3.2, U13.2 (VOUT); also elsewhere on the board
BATT_IN: CON7.+, R33.1; also elsewhere on the board
BATT_SENSE: R32.1, R33.2, U4.4 (AIN0)
CHASSIS: JP2.1
GND: C31.2 (-), C32.2 (-), C33.2 (-), C34.2 (-), C35.2 (-), C37.2, C38.2, C39.1, CON1.-, CON2.-, CON3.-, CON4.-, CON7.-, J1.2, J1.3, J4.2, J5.2, J6.2, J7.2, JP1.2, JP1.4, JP1.6, JP1.8, JP1.10, JP1.12, JP2.2, LED1.C, LED2.C, LED3.C, LED4.C, R31.2, R32.2, R34.2, R37.2, U4.1 (ADDR), U4.3 (GND), U13.1 (GND); also elsewhere on the board
MOTOR_PULLUP: J9.1; also elsewhere on the board
MOTOR_V+: C31.1 (+), C32.1 (+), C33.1 (+), C34.1 (+), C35.1 (+), CON1.+, CON2.+, CON3.+, CON4.+, R29.1, R36.1; also elsewhere on the board
unnamed: LED4.A, R29.2
unnamed: R26.2, R31.1, U4.5 (AIN1)
unnamed: J2.1, J9.2
unnamed: R34.1, R35.2, U4.6 (AIN2)
unnamed: J3.1, J8.2
unnamed: R36.2, R37.1, U4.7 (AIN3)
unnamed: LED3.A, R25.2
unnamed: LED2.A, R22.2
unnamed: LED1.A, R19.2
PS_IN: J1.1, R26.1; also elsewhere on the board
SCL: J10.2, R23.2, U4.10 (SCL)
SDA: J10.1, R24.2, U4.9 (SDA)
SYSTEM_IN: C38.1, R25.1, U13.3 (VIN); also elsewhere on the board
SYSTEM_PULLUP: J2.2, J8.1; also elsewhere on the board
SYSTEM_SWITCHED: JP1.5, JP1.7; also elsewhere on the board
V_ADJ: J4.1, J7.1, JP1.9, JP1.11, R22.1, R35.1; also elsewhere on the board

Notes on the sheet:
Power Supply Input
Battery Input
RED, 2.2v, 20mA
GREEN, 3.2V, 20mA
AMBER, 2.0v, 5mA
BLUE, 2.9v, 5mA
Power Outputs
Power Expansion Port
System Bulk Capacitance
Power Status LEDs
Emergency Stop Ports
Motor Power Ports
Always-on 5v Regulator
GND to Robot Chassis Jumper
I²C Address is 1001000
4 Channel I2C ADC

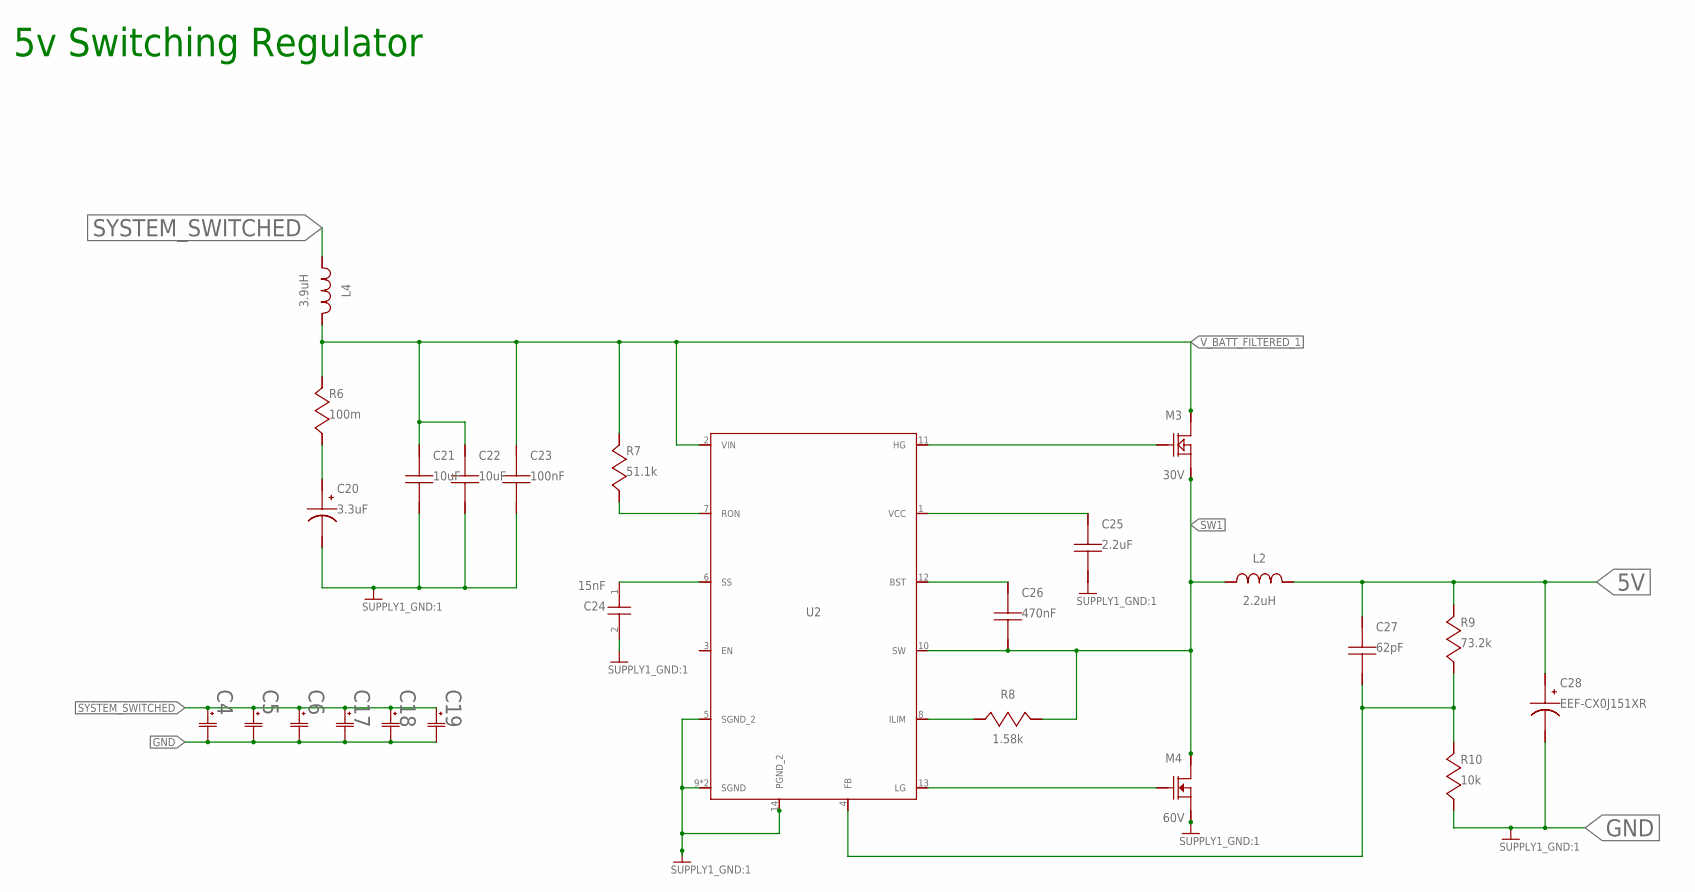
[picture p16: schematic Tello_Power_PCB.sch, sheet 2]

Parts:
C4, C5, C6, C17, C18, C19: PCR1H820MCL1GS_PCR1H820MCL1GS; PCR1H820MCL1GS_CAP_PC_10X8_NCH
C20: 3.3uF; 5V-LM3150MH_6032-28
C21, C22: 10uF; 5V-LM3150MH_0805
C23: 100nF; 5V-LM3150MH_0603
C24: 15nF; CGA4F2C0G1H153J085AA_CAPC2012X100N
C25: 2.2uF; 5V-LM3150MH_0805
C26: 470nF; 5V-LM3150MH_1206
C27: 62pF; 5V-LM3150MH_0805
C28: EEF-CX0J151XR; 5V-LM3150MH_C2917
L2: 2.2uH; 5V-LM3150MH_XAL5030
L4: 3.9uH; 5V-LM3150MH_IND_NPI43C
M3: 30V; 5V-LM3150MH_TRANS_NEXFET_Q5A
M4: 60V; 5V-LM3150MH_TRANS_NEXFET_Q5A
R6: 100m; 5V-LM3150MH_0603
R7: 51.1k; 5V-LM3150MH_0805
R8: 1.58k; 5V-LM3150MH_0805
R9: 73.2k; 5V-LM3150MH_0805
R10: 10k; 5V-LM3150MH_0805
U2: 5V-LM3150MH_LM3150MH/NOPB; 5V-LM3150MH_MXA14A

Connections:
5V: C27.1, C28.P$1 (+), L2.2, R9.1; also elsewhere on the board
GND: C4.2, C5.2, C6.2, C17.2, C18.2, C19.2, C20.2 (-), C21.2, C22.2, C23.2, C24.2, C25.2, C28.P$2 (-), M4.1 (SOURCE), M4.2 (SOURCE), M4.3 (SOURCE), R10.2, U2.5 (SGND_2), U2.9 (SGND), U2.14 (PGND_2), U2.15 (SGND); also elsewhere on the board
unnamed: R7.2, U2.7 (RON)
unnamed: C24.1, U2.6 (SS)
unnamed: C20.1 (+), R6.2
unnamed: R8.2, U2.8 (ILIM)
unnamed: C26.1, U2.12 (BST)
unnamed: C25.1, U2.1 (VCC)
unnamed: M3.4 (GATE), U2.11 (HG)
unnamed: M4.4 (GATE), U2.13 (LG)
unnamed: C27.2, R9.2, R10.1, U2.4 (FB)
SW1: C26.2, L2.1, M3.1 (SOURCE), M3.2 (SOURCE), M3.3 (SOURCE), M4.5 (DRAIN), M4.6 (DRAIN), M4.7 (DRAIN), M4.8 (DRAIN), M4.9 (DRAIN), R8.1, U2.10 (SW)
SYSTEM_SWITCHED: C4.1, C5.1, C6.1, C17.1, C18.1, C19.1, L4.1; also elsewhere on the board
V_BATT_FILTERED_1: C21.1, C22.1, C23.1, L4.2, M3.5 (DRAIN), M3.6 (DRAIN), M3.7 (DRAIN), M3.8 (DRAIN), M3.9 (DRAIN), R6.1, R7.1, U2.2 (VIN)

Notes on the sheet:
5v Switching Regulator

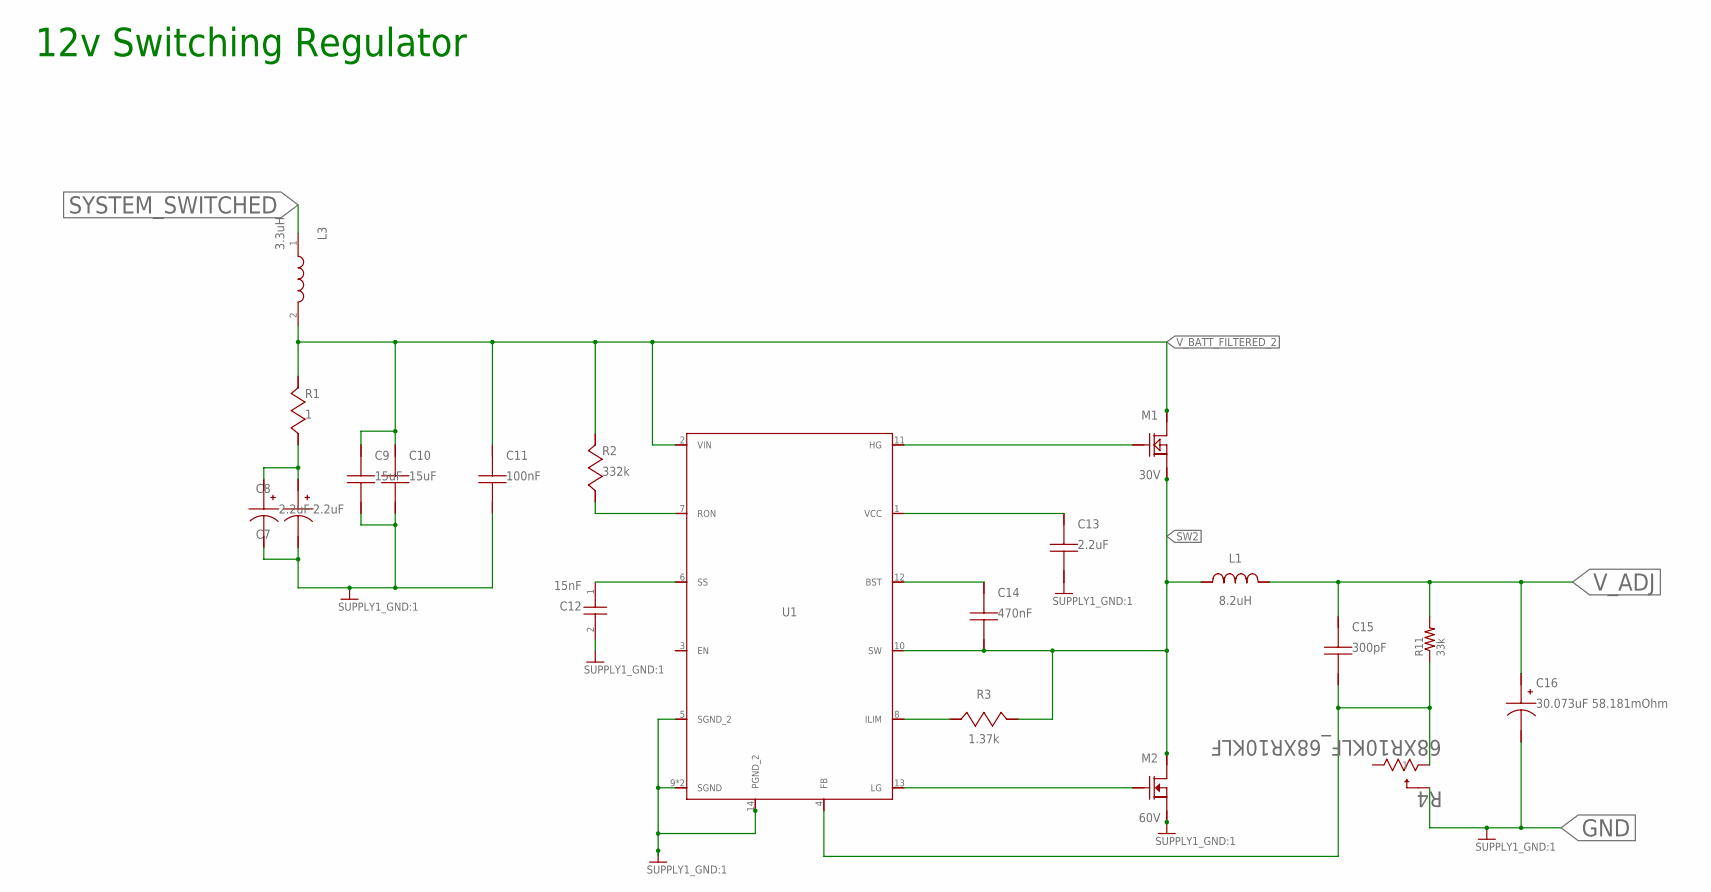
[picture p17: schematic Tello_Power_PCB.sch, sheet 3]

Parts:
C7, C8: 2.2uF; 12V--LM3150_3528-21
C9, C10: 15uF; 12V--LM3150_0805:1
C11: 100nF; 12V--LM3150_0402
C12: 15nF; CGA4F2C0G1H153J085AA_CAPC2012X100N
C13: 2.2uF; 12V--LM3150_0805:1
C14: 470nF; 12V--LM3150_1206:1
C15: 300pF; 12V--LM3150_0805:1
C16: 30.073uF 58.181mOhm; 12V--LM3150_PCV1E330MCL1GS
L1: 8.2uH; 12V--LM3150_WE-LHMI_8040
L3: 3.3uH; XAL4030-332MEB_XAL4030-332MEB
M1: 30V; 12V--LM3150_TRANS_NEXFET_Q5A:1
M2: 60V; 12V--LM3150_TRANS_NEXFET_Q5A:1
R1: 1; 12V--LM3150_0402
R2: 332k; 12V--LM3150_0805:1
R3: 1.37k; 12V--LM3150_0805:1
R4: 68XR10KLF_68XR10KLF; 68XR10KLF_RES3_68X_TTE
R11: 33k; RCL_R0805
U1: 5V-LM3150MH_LM3150MH/NOPB; 5V-LM3150MH_MXA14A

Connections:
GND: C7.2 (-), C8.2 (-), C9.2, C10.2, C11.2, C12.2, C13.2, C16.P$3 (-), M2.1 (SOURCE), M2.2 (SOURCE), M2.3 (SOURCE), R4.2, U1.5 (SGND_2), U1.9 (SGND), U1.14 (PGND_2), U1.15 (SGND); also elsewhere on the board
unnamed: C7.1 (+), C8.1 (+), R1.2
unnamed: R2.2, U1.7 (RON)
unnamed: C12.1, U1.6 (SS)
unnamed: R3.2, U1.8 (ILIM)
unnamed: C14.1, U1.12 (BST)
unnamed: C13.1, U1.1 (VCC)
unnamed: M1.4 (GATE), U1.11 (HG)
unnamed: M2.4 (GATE), U1.13 (LG)
unnamed: C15.2, R4.3 (1), R11.1, U1.4 (FB)
SW2: C14.2, L1.1, M1.1 (SOURCE), M1.2 (SOURCE), M1.3 (SOURCE), M2.5 (DRAIN), M2.6 (DRAIN), M2.7 (DRAIN), M2.8 (DRAIN), M2.9 (DRAIN), R3.1, U1.10 (SW)
SYSTEM_SWITCHED: L3.1; also elsewhere on the board
V_ADJ: C15.1, C16.P$1 (+), L1.2, R11.2; also elsewhere on the board
V_BATT_FILTERED_2: C9.1, C10.1, C11.1, L3.2, M1.5 (DRAIN), M1.6 (DRAIN), M1.7 (DRAIN), M1.8 (DRAIN), M1.9 (DRAIN), R1.1, R2.1, U1.2 (VIN)

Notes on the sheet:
12v Switching Regulator

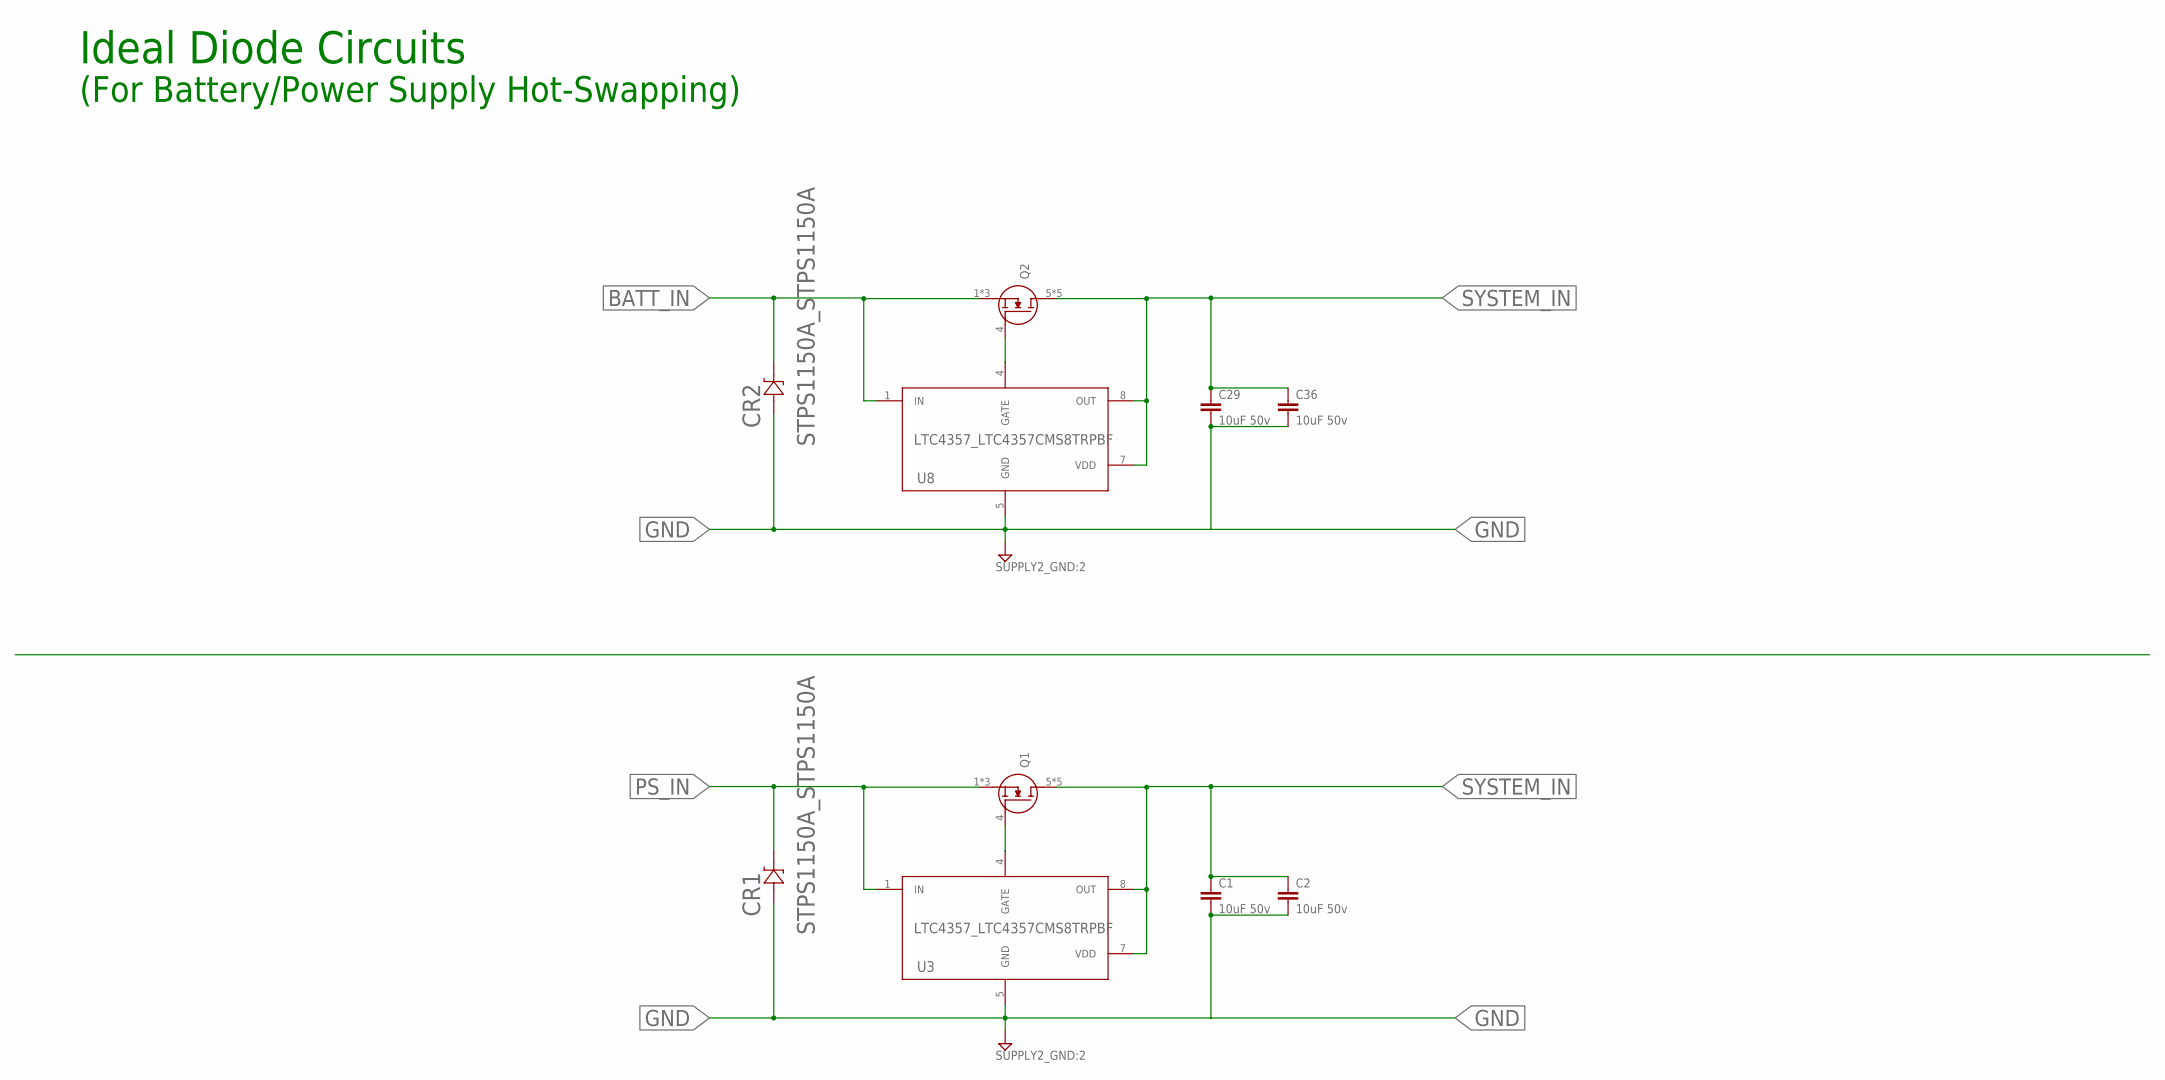
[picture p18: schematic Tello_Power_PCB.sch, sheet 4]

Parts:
C1, C2, C29, C36: 10uF 50v; RCL_C1206
CR1, CR2: STPS1150A_STPS1150A; STPS1150A_SMA_STM
Q1, Q2: BSC027N06LS5ATMA1_BSC027N06LS5ATMA1
U3, U8: LTC4357_LTC4357CMS8TRPBF; LTC4357_MSOP-8_MS_LIT

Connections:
BATT_IN: CR2.1, Q2.1 (S), Q2.2 (S), Q2.3 (S), U8.1 (IN); also elsewhere on the board
GND: C1.2, C2.2, C29.2, C36.2, CR1.2, CR2.2, U3.5 (GND), U8.5 (GND); also elsewhere on the board
unnamed: Q1.4 (G), U3.4 (GATE)
unnamed: Q2.4 (G), U8.4 (GATE)
PS_IN: CR1.1, Q1.1 (S), Q1.2 (S), Q1.3 (S), U3.1 (IN); also elsewhere on the board
SYSTEM_IN: C1.1, C2.1, C29.1, C36.1, Q1.5 (D), Q1.6 (D), Q1.7 (D), Q1.8 (D), Q1.9 (D), Q2.5 (D), Q2.6 (D), Q2.7 (D), Q2.8 (D), Q2.9 (D), U3.7 (VDD), U3.8 (OUT), U8.7 (VDD), U8.8 (OUT); also elsewhere on the board

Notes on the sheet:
Ideal Diode Circuits
(For Battery/Power Supply Hot-Swapping)

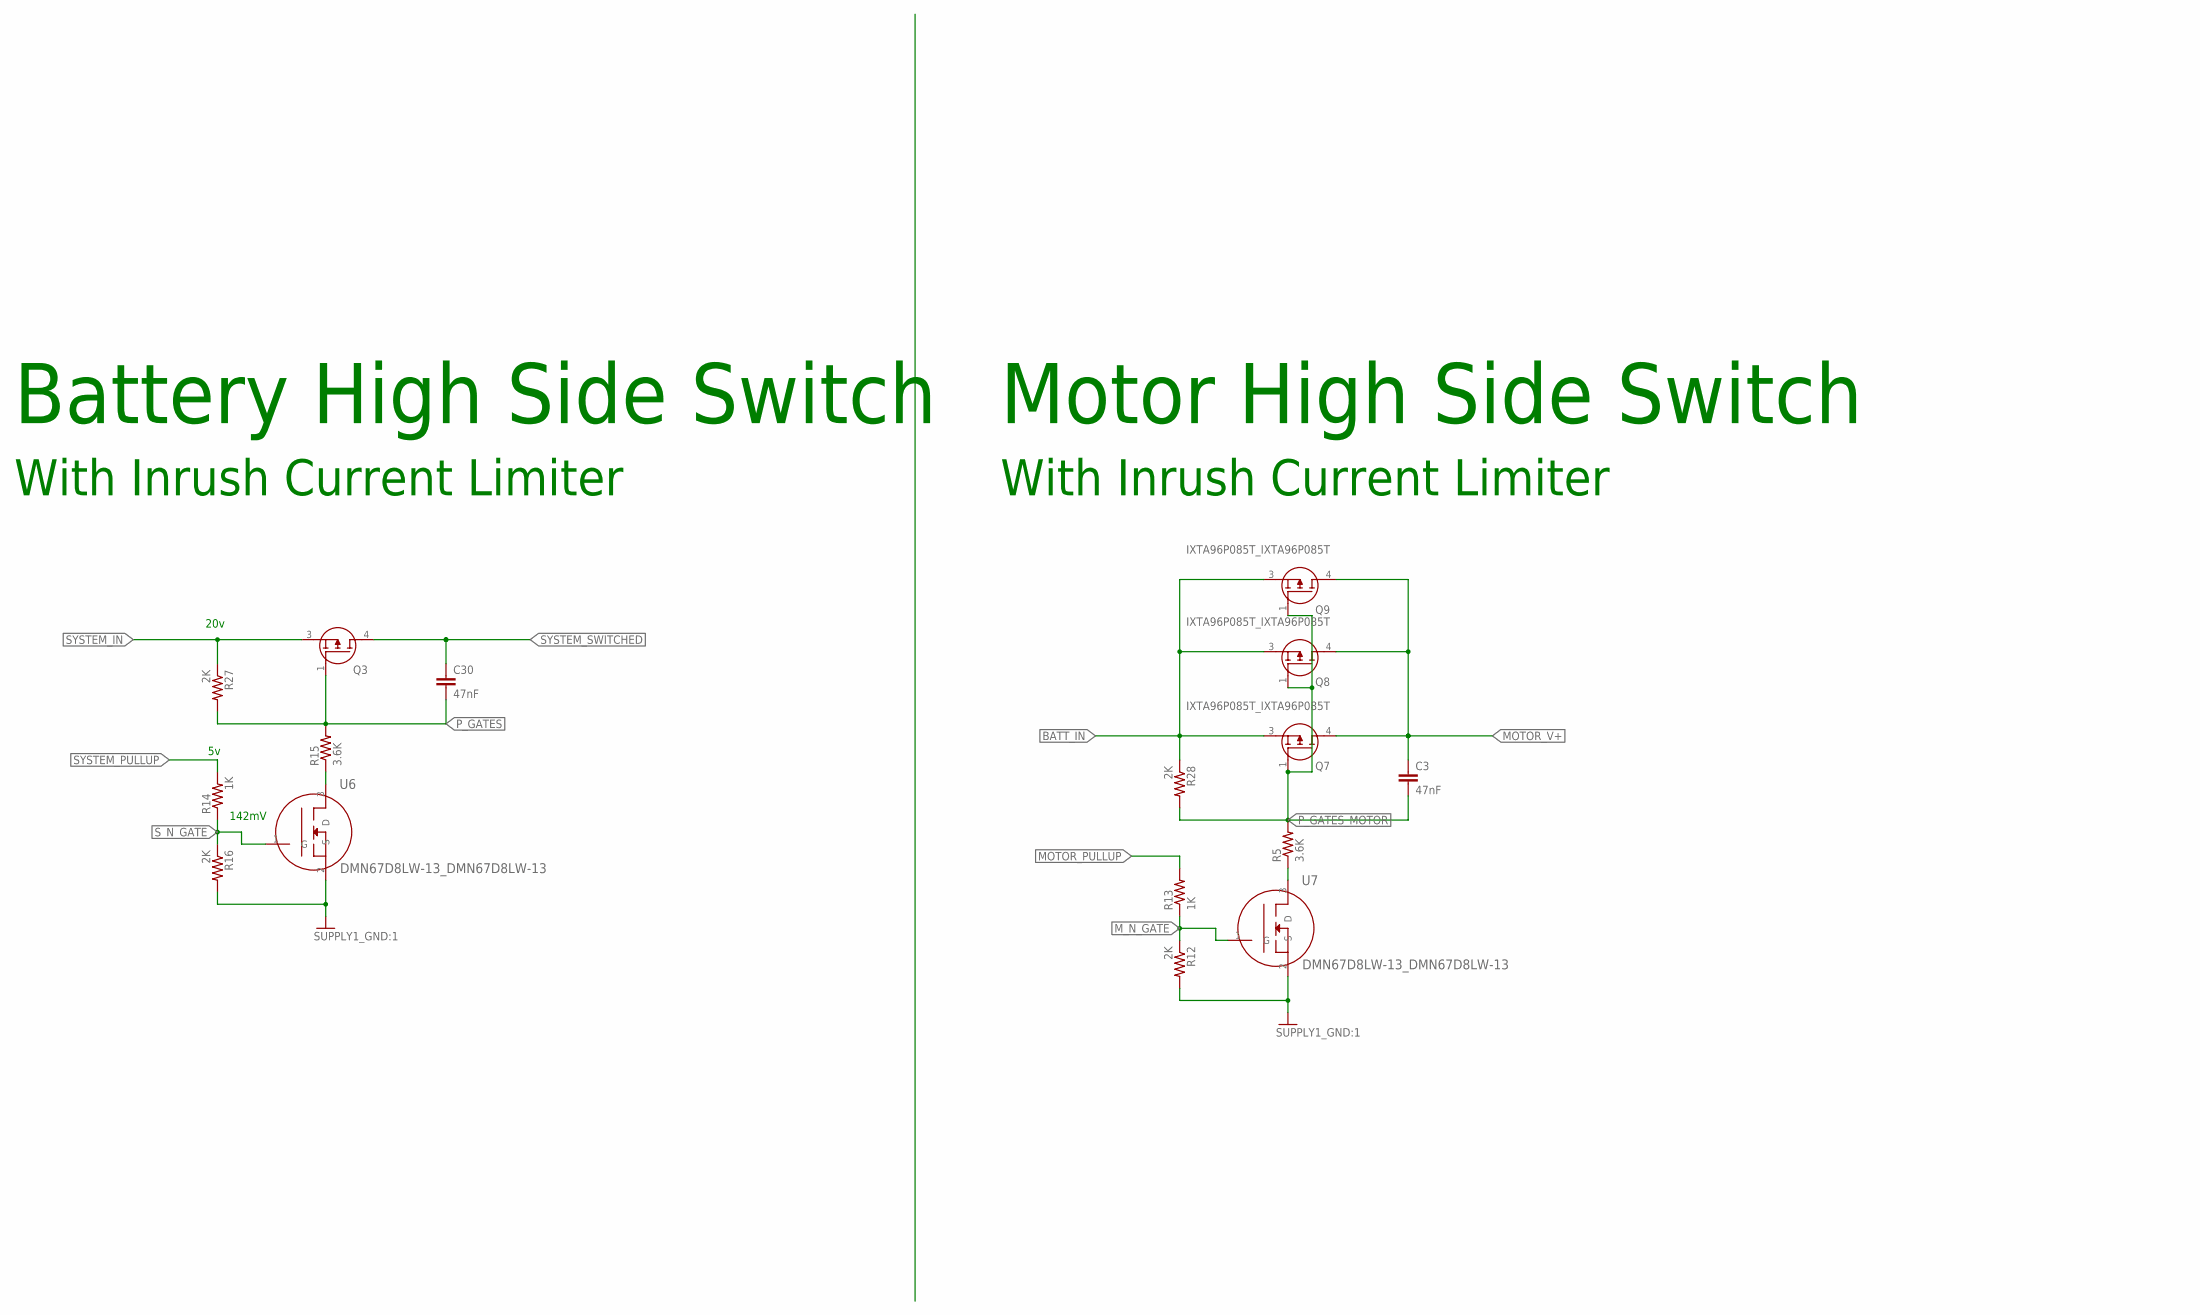
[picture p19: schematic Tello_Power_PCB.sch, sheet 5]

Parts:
C3, C30: 47nF; RCL_C0603
Q3, Q7, Q8, Q9: IXTA96P085T_IXTA96P085T
R5, R15: 3.6K; RCL_R0603
R12, R16, R27, R28: 2K; RCL_R0603
R13, R14: 1K; RCL_R0603
U6, U7: DMN67D8LW-13_DMN67D8LW-13; DMN67D8LW-13_DMN67D8LW-13_DIO

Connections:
BATT_IN: Q7.3 (S), Q8.3 (S), Q9.3 (S), R28.1; also elsewhere on the board
GND: R12.2, R16.2, U6.2 (S), U7.2 (S); also elsewhere on the board
MOTOR_PULLUP: R13.2; also elsewhere on the board
MOTOR_V+: C3.1, Q7.4 (D), Q8.4 (D), Q9.4 (D); also elsewhere on the board
M_N_GATE: R12.1, R13.1, U7.1 (G); also elsewhere on the board
unnamed: R5.1, U7.3 (D)
unnamed: R15.1, U6.3 (D)
P_GATES: C30.2, Q3.1 (G), R15.2, R27.2
P_GATES_MOTOR: C3.2, Q7.1 (G), Q8.1 (G), Q9.1 (G), R5.2, R28.2
SYSTEM_IN: Q3.3 (S), R27.1; also elsewhere on the board
SYSTEM_PULLUP: R14.2; also elsewhere on the board
SYSTEM_SWITCHED: C30.1, Q3.4 (D); also elsewhere on the board
S_N_GATE: R14.1, R16.1, U6.1 (G); also elsewhere on the board

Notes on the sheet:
Battery High Side Switch
With Inrush Current Limiter
Motor High Side Switch
20v
142mV

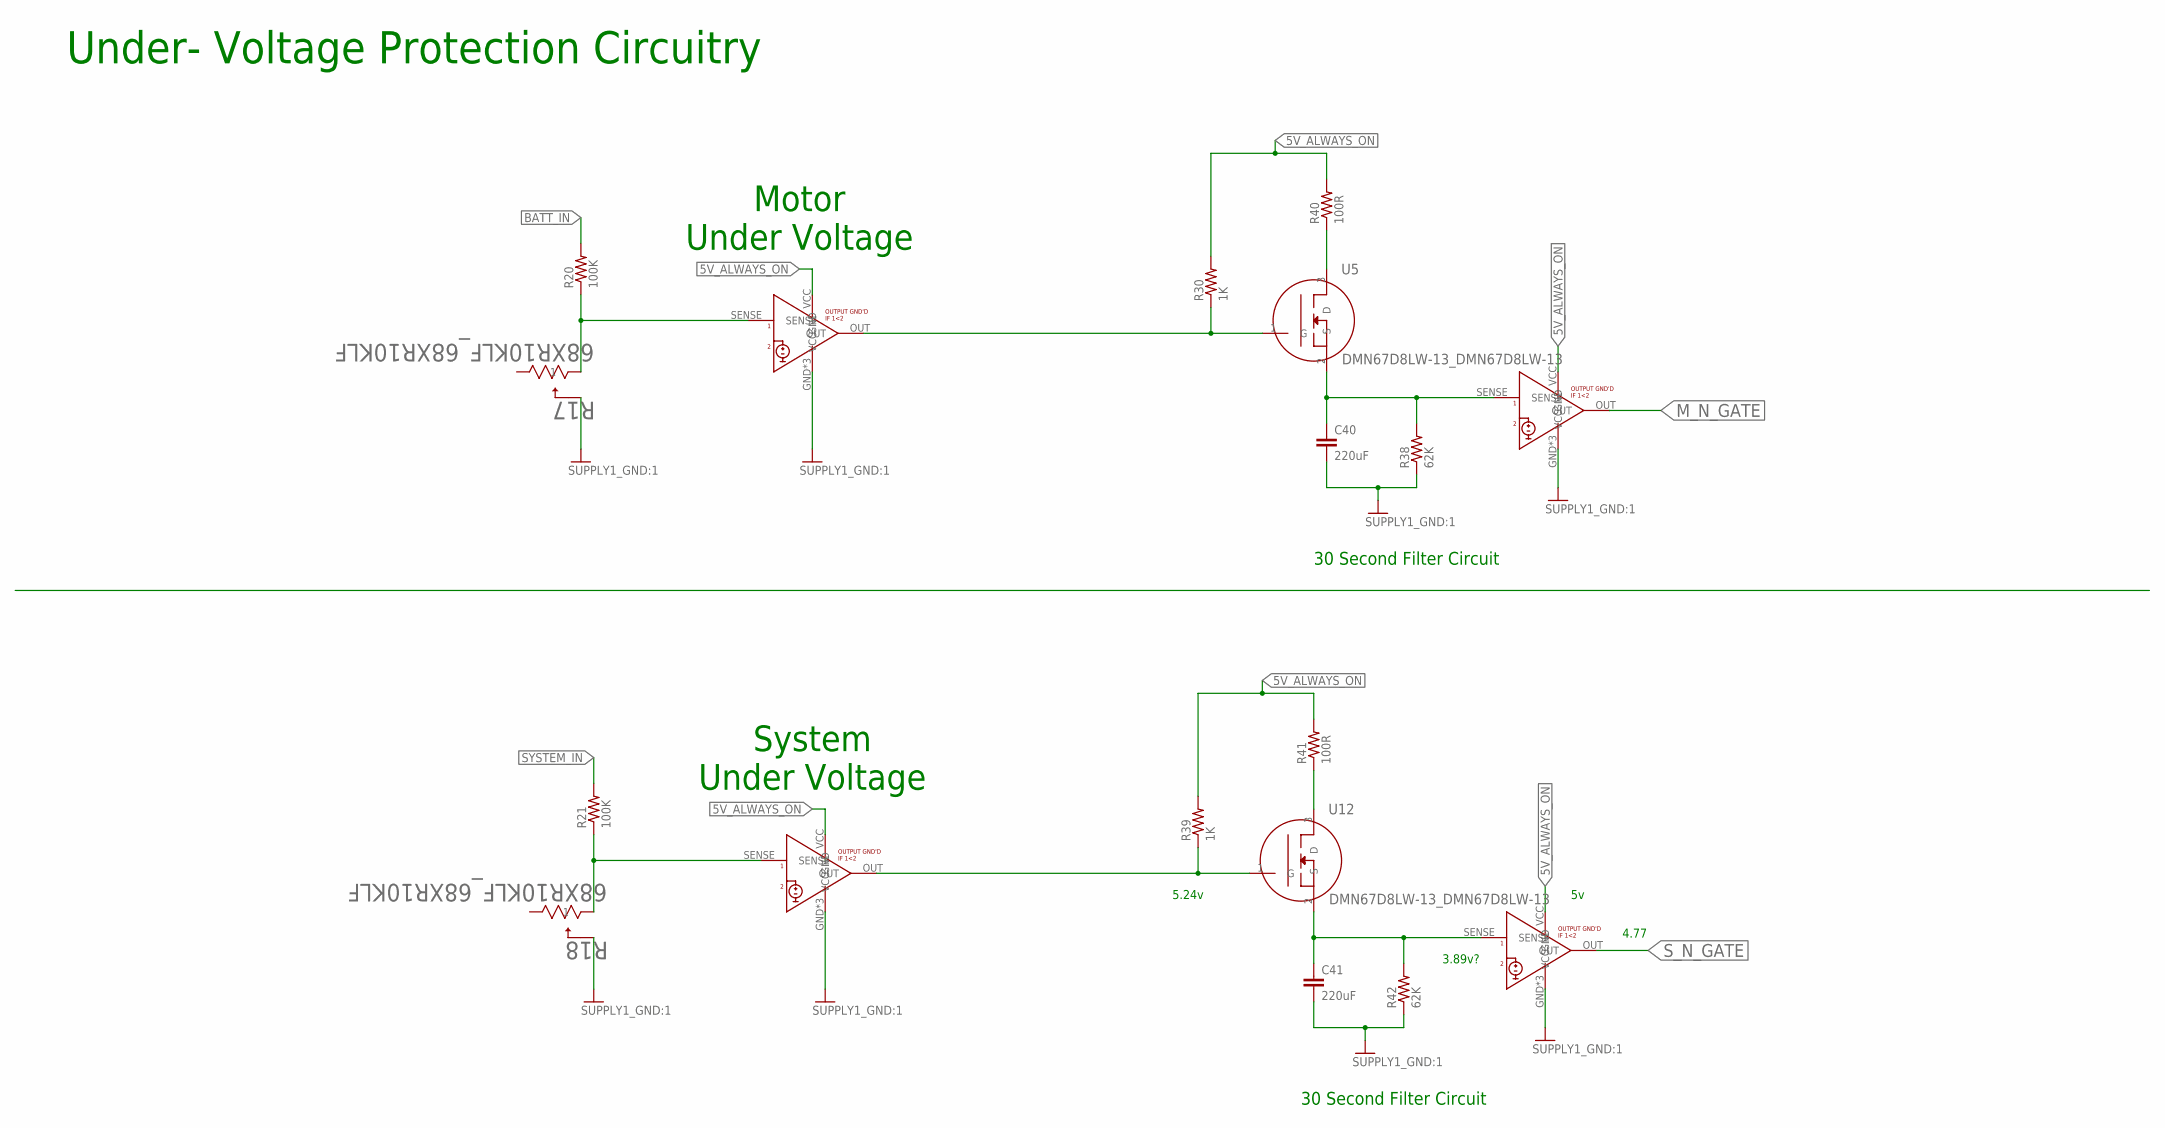
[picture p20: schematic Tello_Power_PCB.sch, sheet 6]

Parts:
C40, C41: 220uF; RCL_C1210
R17, R18: 68XR10KLF_68XR10KLF; 68XR10KLF_RES3_68X_TTE
R20, R21: 100K; RCL_R0603
R30, R39: 1K; RCL_R0603
R38, R42: 62K; RCL_R0603
R40, R41: 100R; RCL_R0603
U5, U12: DMN67D8LW-13_DMN67D8LW-13; DMN67D8LW-13_DMN67D8LW-13_DIO
U9, U10, U11, U14: TLV6713DDC_TLV6713DDCTDDC0006A_M; TLV6713DDC_DDC0006A_M

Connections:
5V_ALWAYS_ON: R30.2, R39.2, R40.2, R41.2, U9.VCC, U10.VCC, U11.VCC, U14.VCC; also elsewhere on the board
BATT_IN: R20.2; also elsewhere on the board
GND: C40.2, C41.2, R17.2, R18.2, R38.1, R42.1, U9.GND, U9.GND@1 (GND), U9.GND@2 (GND), U10.GND, U10.GND@1 (GND), U10.GND@2 (GND), U11.GND, U11.GND@1 (GND), U11.GND@2 (GND), U14.GND, U14.GND@1 (GND), U14.GND@2 (GND); also elsewhere on the board
M_N_GATE: U11.OUT; also elsewhere on the board
unnamed: R30.1, U5.1 (G), U10.OUT
unnamed: R18.3 (1), R21.1, U9.SENSE
unnamed: R17.3 (1), R20.1, U10.SENSE
unnamed: C40.1, R38.2, U5.2 (S), U11.SENSE
unnamed: R40.1, U5.3 (D)
unnamed: R39.1, U9.OUT, U12.1 (G)
unnamed: R41.1, U12.3 (D)
unnamed: C41.1, R42.2, U12.2 (S), U14.SENSE
SYSTEM_IN: R21.2; also elsewhere on the board
S_N_GATE: U14.OUT; also elsewhere on the board

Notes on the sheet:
System Under Voltage
Motor Under Voltage
30 Second Filter Circuit
Under- Voltage Protection Circuitry
3.89v?
5.24v
4.77

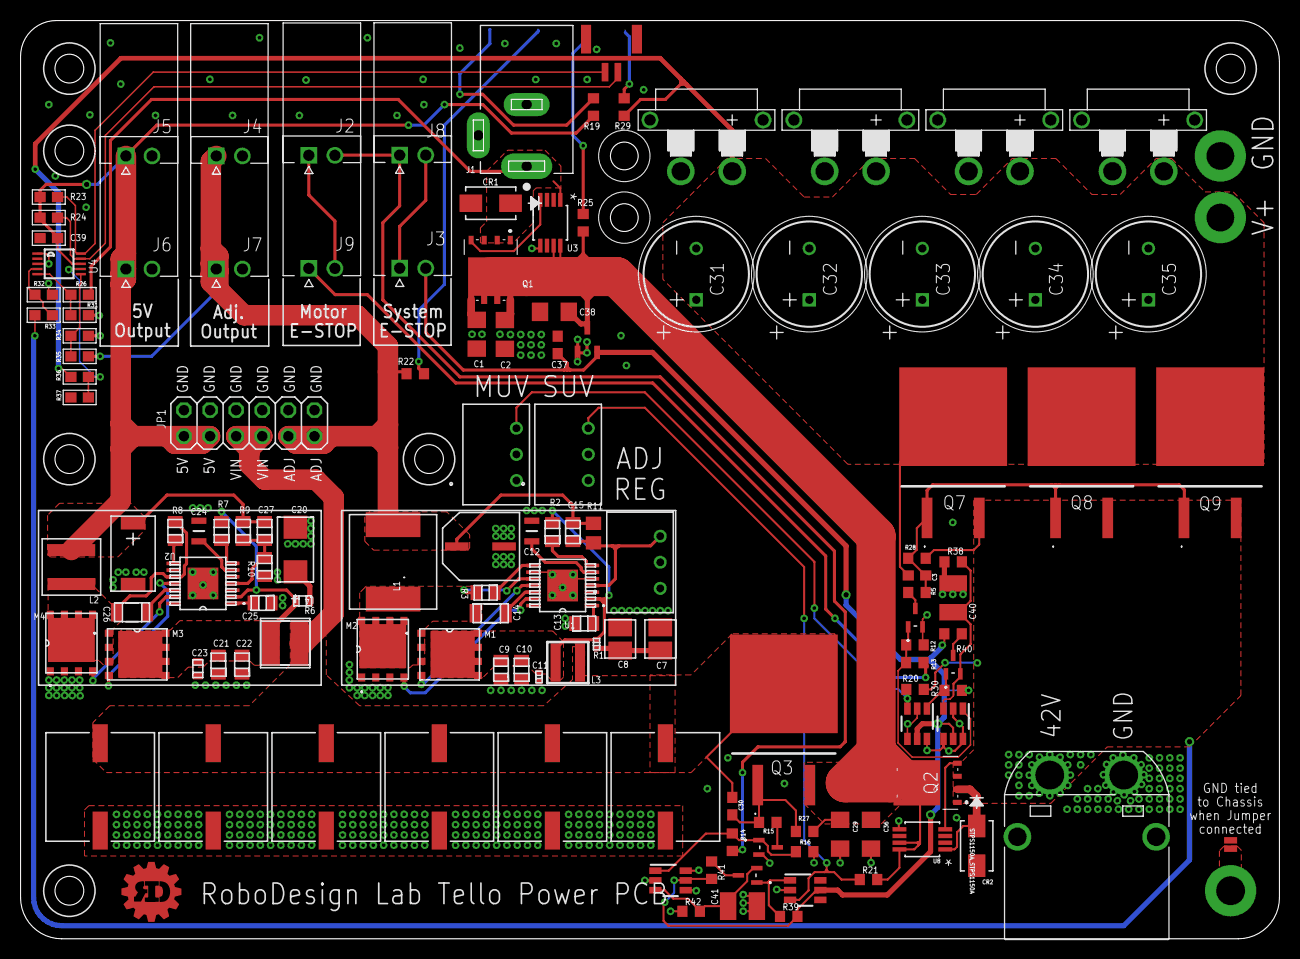
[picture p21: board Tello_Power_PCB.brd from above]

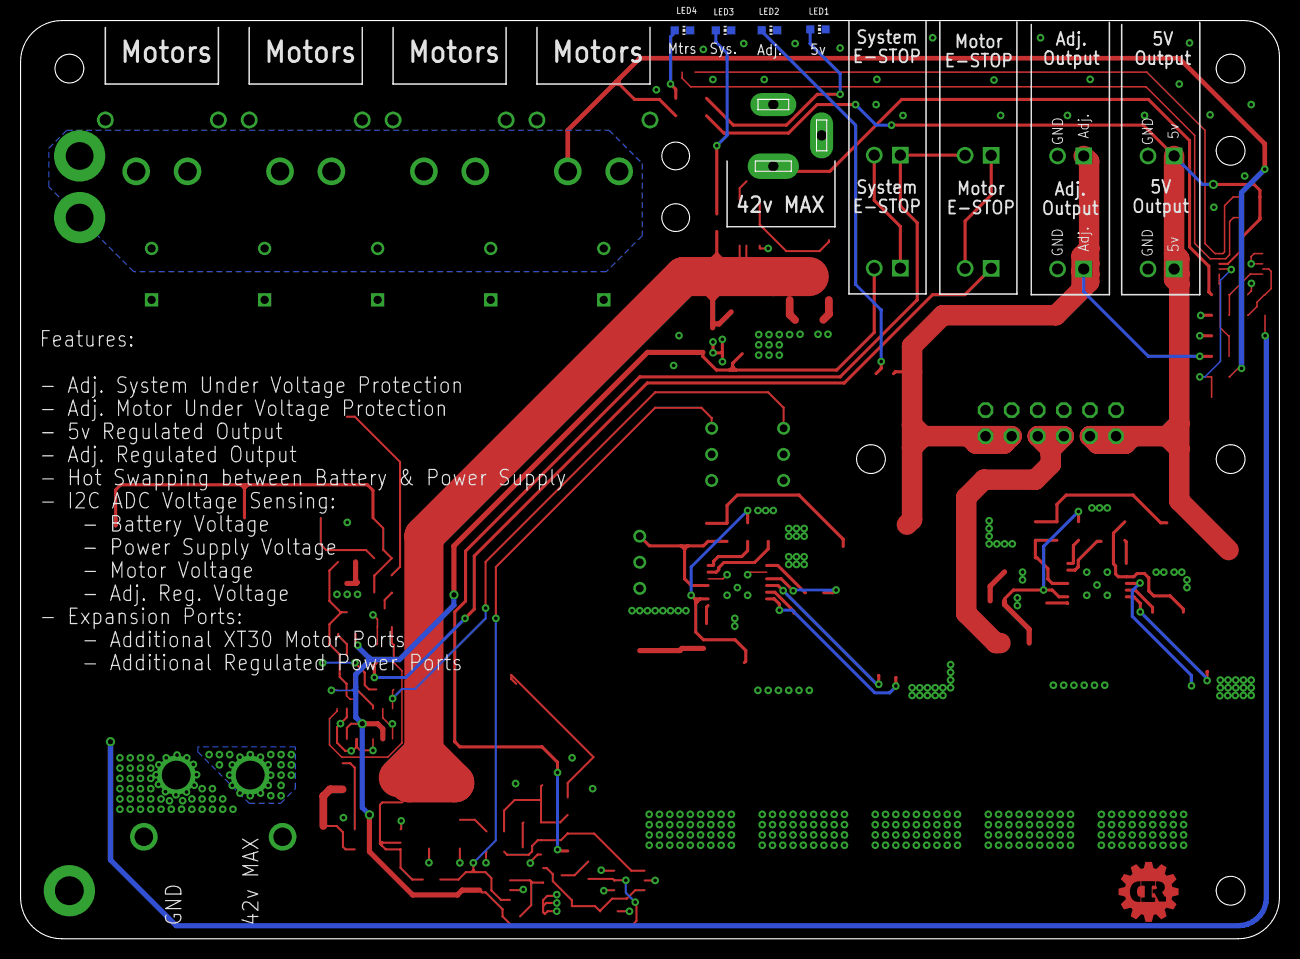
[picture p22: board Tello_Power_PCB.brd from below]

Board: 4 copper layers, 122.5 x 89.3 mm, 134 parts (4 on the bottom side), 61 nets.

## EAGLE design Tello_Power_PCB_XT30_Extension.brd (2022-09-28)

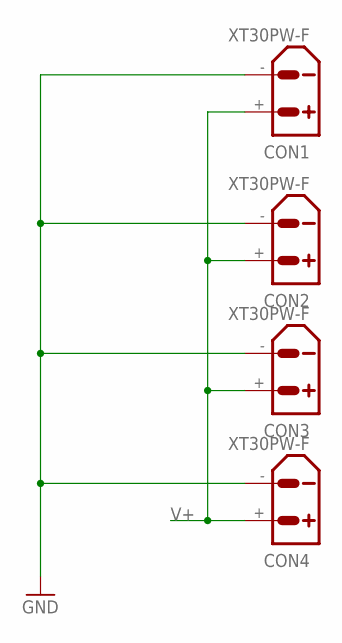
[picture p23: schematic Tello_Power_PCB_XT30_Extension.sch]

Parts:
CON1, CON2, CON3, CON4: XT30PW-F

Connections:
GND: CON1.-, CON2.-, CON3.-, CON4.-
V+: CON1.+, CON2.+, CON3.+, CON4.+

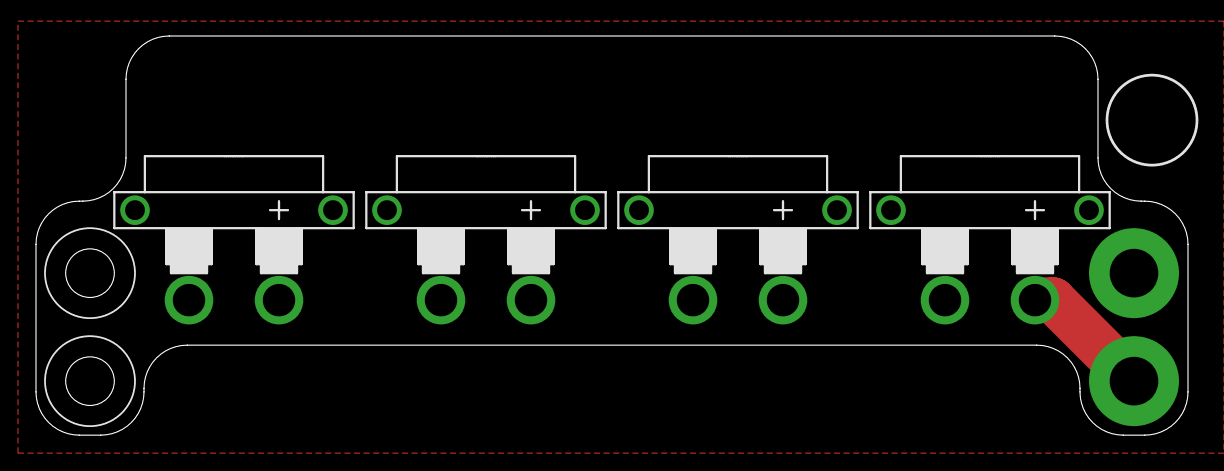
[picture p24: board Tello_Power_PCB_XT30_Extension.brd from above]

Board: 2 copper layers, 64.0 x 22.2 mm, 4 parts (0 on the bottom side), 2 nets.

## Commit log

2022-09-12 Started laying out PCB
    [Tello_Power_PCB.brd, Tello_Power_PCB.sch]
2022-09-16 Most things laid out
    [Tello_Power_PCB.brd, Tello_Power_PCB.sch]
2022-09-16 added XT30 Expansion PCB
    [Tello_Power_PCB_XT30_Extension.brd, Tello_Power_PCB_XT30_Extension.sch]
2022-09-19 Added motor PMOS stage
    [Tello_Power_PCB.brd, Tello_Power_PCB.sch]
2022-09-19 Routed about half of pcb
    [Tello_Power_PCB.brd, Tello_Power_PCB.sch]
2022-09-22 Made big changes to power distr.
    [Tello_Power_PCB.brd, Tello_Power_PCB.sch]
2022-09-23 added ADC and 5V-AO
    [Tello_Power_PCB.brd, Tello_Power_PCB.sch]
2022-09-23 Finished Routing PCB, Needs Design Review
    [Tello_Power_PCB.brd, Tello_Power_PCB.sch]
2022-09-24 added UV 30s delay circuit
    [Tello_Power_PCB.brd, Tello_Power_PCB.sch]
2022-09-27 Organized Schematic, Ready for Detailed Review
    [Tello_Power_PCB.brd, Tello_Power_PCB.sch]
2022-09-27 Increased internal GND conn. widths
    [Tello_Power_PCB.brd]
2022-09-27 Organized Schematic
    [Tello_Power_PCB.brd, Tello_Power_PCB.sch]
2022-09-27 Review Finished
    [Tello_Power_PCB.sch]
2022-09-28 Added mfg files and renders
    [Tello_Power_PCB.brd, Tello_Power_PCB.sch, Tello_Power_PCB_XT30_Extension.brd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]
2022-09-28 added 3d model
    [Tello_Power_PCB.SLDASM, Tello_Power_PCB.brd, Tello_Power_PCB.sch]
2023-10-02 updated readme photos
    [Power_PCB_Cover.3mf, Power_PCB_Cover.SLDPRT, Power_PCB_Cover.STL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]
2023-10-18 updated high side switch resistors
    [Tello_Power_PCB.brd, Tello_Power_PCB.sch]

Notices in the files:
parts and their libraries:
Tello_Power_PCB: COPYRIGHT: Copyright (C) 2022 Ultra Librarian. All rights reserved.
